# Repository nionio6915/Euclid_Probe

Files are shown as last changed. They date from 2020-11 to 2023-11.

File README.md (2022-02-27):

# EUCLID PROBE

The highly accurate, magneticaly coupled Z-Probe that is not affected by bed temp, bed material, magnetism or surface treatment.   

The probe can be configured to be used as Z-endstop, be manually or automatically deployed via gcode macros, and can take advantage of the firmware's probe pickup detection scheme to ensure pickup/release. It uses screw attached magnets for both mechanical coupling and for electrical contact. The Z-Probe circuit is completed when the probe is attached. 

The unique dock design securely captures the probe, providing secure and reliable docking and undocking. 

# We have moved all documentation to https://www.euclidprobe.com  
# All data and source files will remain here and be linked from here 

YouTube Channel - https://www.youtube.com/channel/UCIUXRiUfHCOrqRxitcH9O6g

Discussion and support is available as a subgroup to the CroXY Discord- https://discord.gg/jfnVrUx2uK croxy  

Parts kits and fully assembled probes are available for purchase at www.euclidprobe.com. 

The most current info, including printable dock and mount files are also hosted at www.euclidprobe.com.

**<br />This work is licensed under a <a rel="license" href="http://creativecommons.org/licenses/by-nc-sa/4.0/">Creative Commons Attribution-NonCommercial-ShareAlike 4.0 International License</a>.**

## Euclid Probe YouTube Channel 

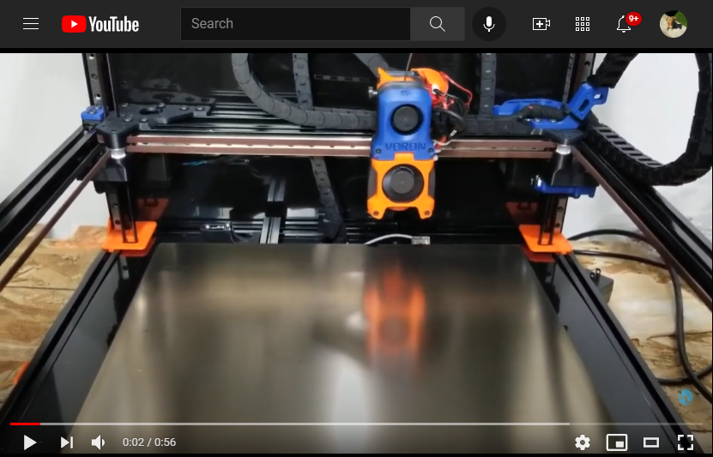
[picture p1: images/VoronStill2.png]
<a href="https://www.youtube.com/channel/UCIUXRiUfHCOrqRxitcH9O6g" target="new"><br>Euclid Probe YouTube channel</br></a>

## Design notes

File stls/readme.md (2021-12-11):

## Repository of stl's for probe adapters and probe docks. 

CAD files in the CAD directory. 

Docks and adapters are designed to be printed at either 0.2mm or 0.3mm layer heights. The probe dock stl's are offered with both Print In Place supports and withought. The best probe deployment results seem to be had by printing the probe dock upside-down: in the event that the PCB bears against the top of the dock when being deployed, this would be the best, top surface of your print. The bottom of the well surface can be a little rough and uneven.  

Note: there is a 5x5mm pocket to insert an optional magnet or ferrous object to retain the probe in the dock. It is not required. This was utilized in early stages of development and remains a legacy for now. 

**The design of your dock is critical to the sucessfull attaching and detaching of the probe.** The Euclid Probe dock utilizes a well, so that when the probe is stripped from the carraige, it is retained by the stops. Upon probe pickup, the probe PCB must clear the exit slots. Adjust the elevation of either the carraige in the deployment gcode or adjust the dock so that in the coupled condition, the probe will slide out without interference.   

## Mounts
**BLTouch Adapter Mount**
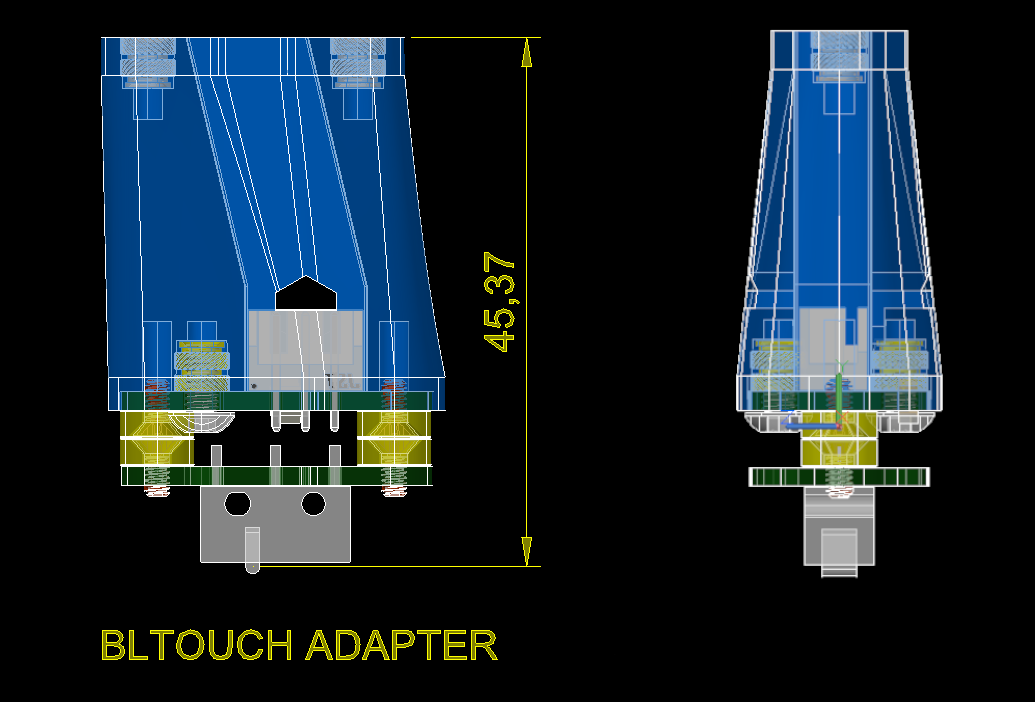
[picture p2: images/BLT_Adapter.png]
BL Touch Adapter
   

**Fixed Frame Dock**
2 Piece design, uses M3 screws and captive nuts to couple the parts. Vertical slots in the mount provide adjustability.     
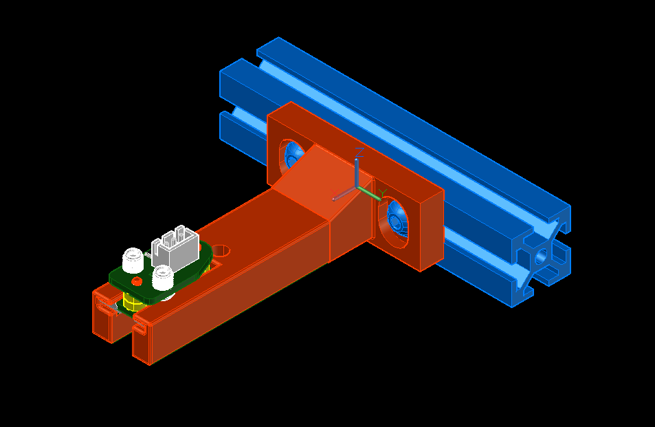
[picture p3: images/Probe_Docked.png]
Probe docked in Frame mounted fixed dock
  

**Movable Bed Dock**  
Uses long style, double taper heatserts for assembly. Mounts to the end of a 2020 bed support rail and is adjustable for height. Allows for interchangeble beds to fit under the mount. Requires a change the Z probe offset constant by the bed thickness on the fly. ( G31 Z-(bed thickness) )     
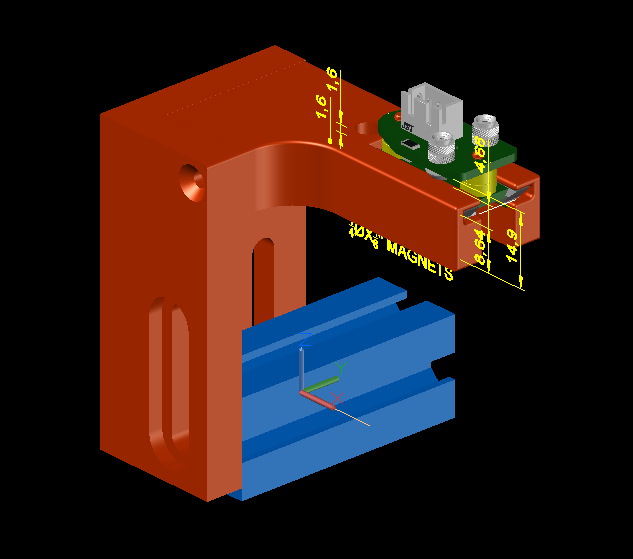
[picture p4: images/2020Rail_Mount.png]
2020 BBed Mount
 

**Dock stub for grafting into your own printer design the business end you need.**  
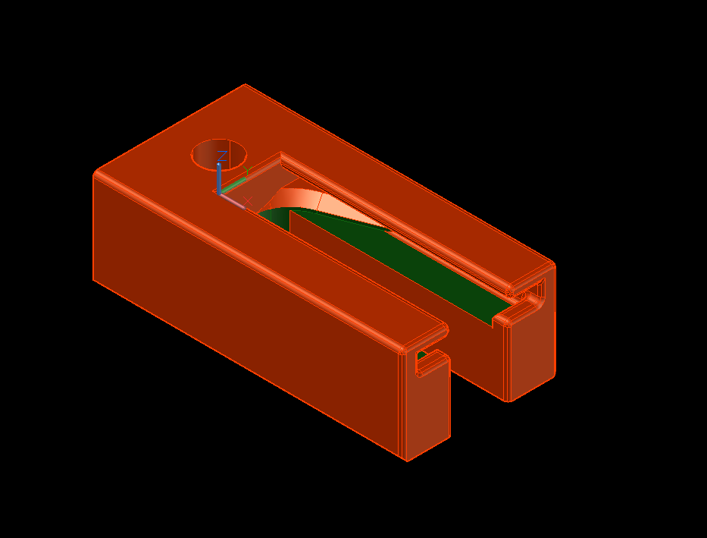
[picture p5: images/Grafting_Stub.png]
Grafting Stub
  

**Omron / Fotec Adapter mount**   
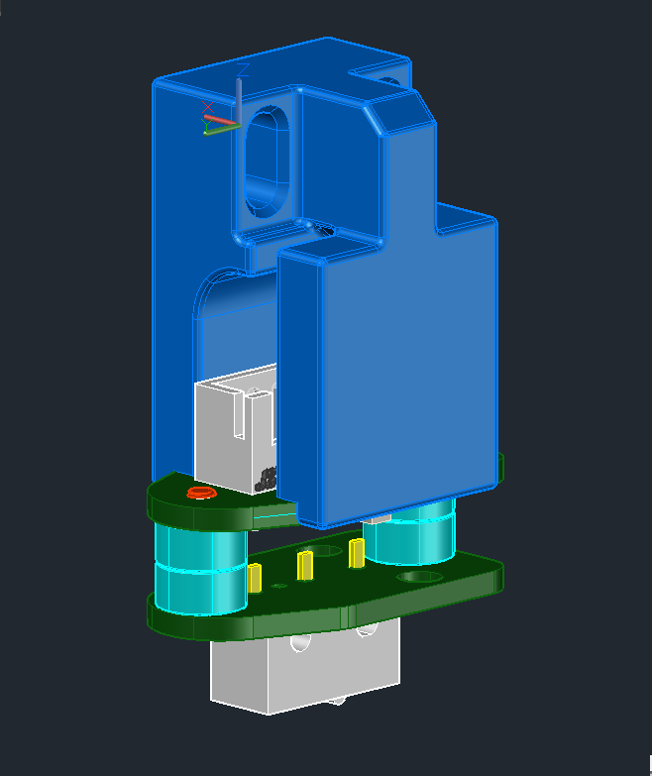
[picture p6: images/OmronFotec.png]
Omron-Fotek
  

**Omron / Fotec 90 Degree Rotation Adapter mount**   
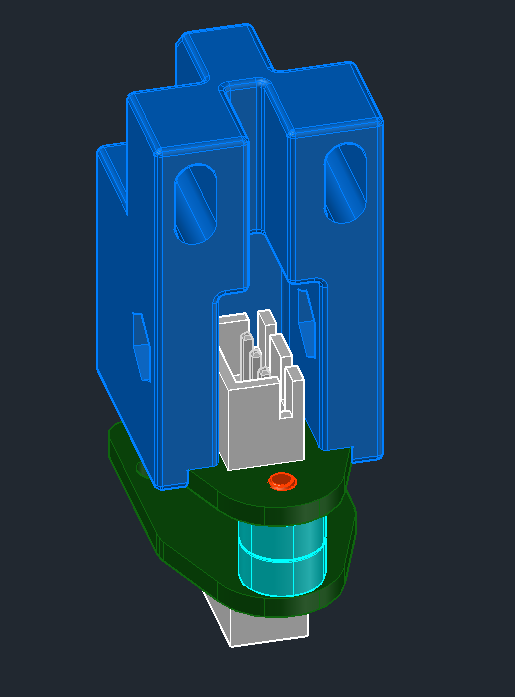
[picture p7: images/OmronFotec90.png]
Omron-Fotek
  

**Railcore Dock & Carriage Adapter**  
Dock based on work originally developed by FeNix. Mount attaches to the carraige plate and is slotted for adjustability. 
Railcore dock is a 2 piece design for adjustability, still under development due to all the variations of Railcore design. Provided with both heatsert and tapped hole options.  
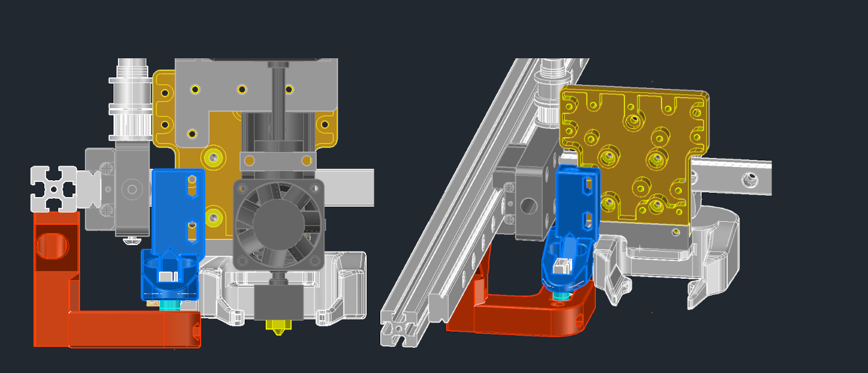
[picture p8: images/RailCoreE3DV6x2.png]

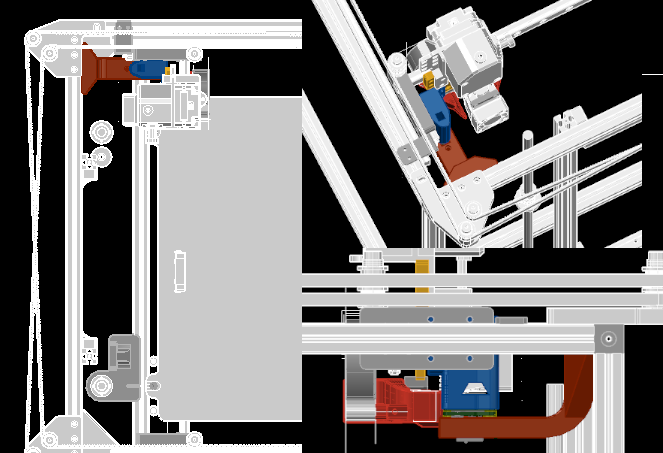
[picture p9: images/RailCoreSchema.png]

iso

**Voron Afterburner V4 User Mod**  
Recessed mount for Euclid probe inte the bottom of the carraige parts, pushing the probed frurther back in Y direction. 
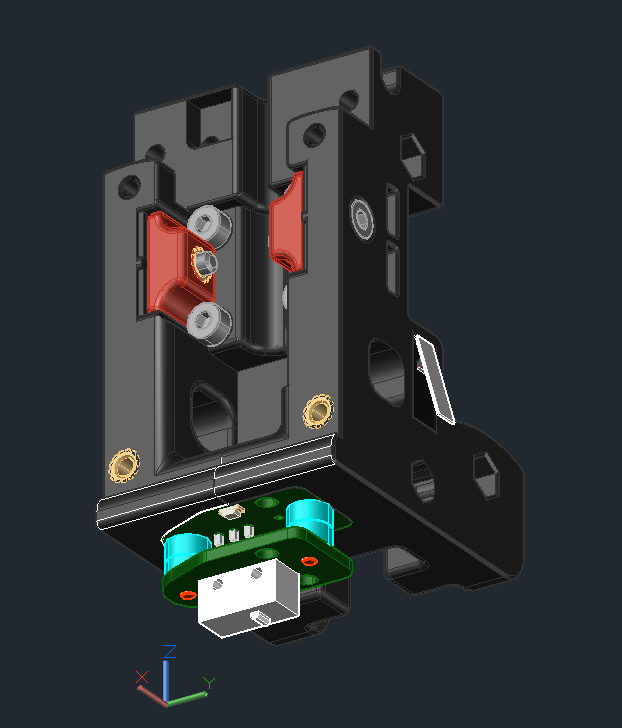
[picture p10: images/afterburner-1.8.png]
 

**Voron 2.4 Frame Mount**  
This mount mounts to the main frame of the printer. Users are cautioned that the probe will always be in the plane of the motion system, and there is always a prossibility of errant probe pickup compared to the bed mounted dock below.   
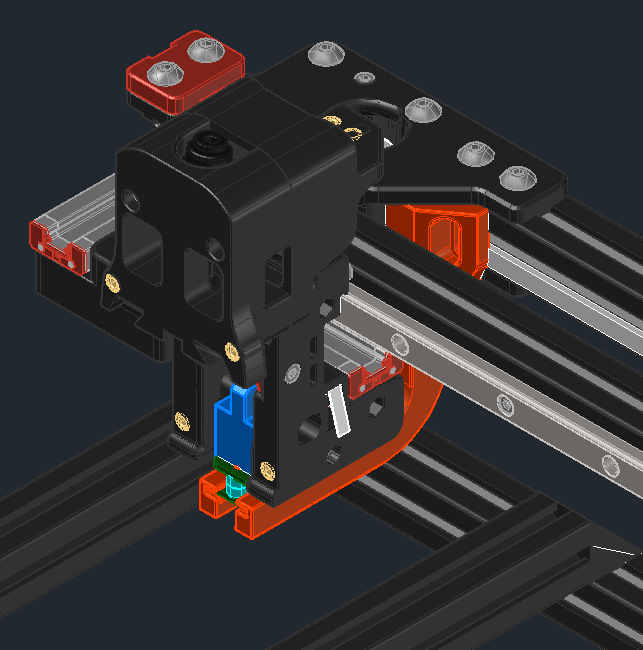
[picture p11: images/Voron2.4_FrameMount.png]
  
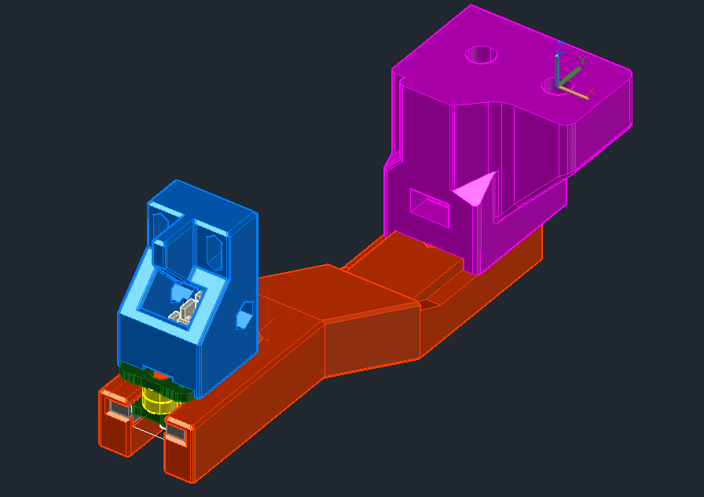
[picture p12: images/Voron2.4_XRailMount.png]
  

**Voron 2.4 Bed Rail Mount**
This mount attaches to the print bed mounting rail. The potential for errant probe pickup is reduced to the Z elevation of the magnet strengths.   
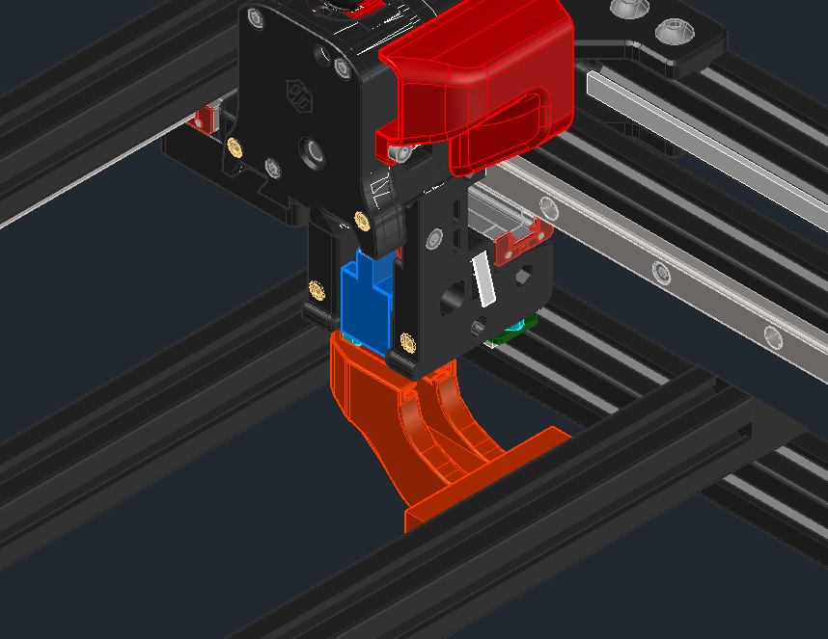
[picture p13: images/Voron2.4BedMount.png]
   
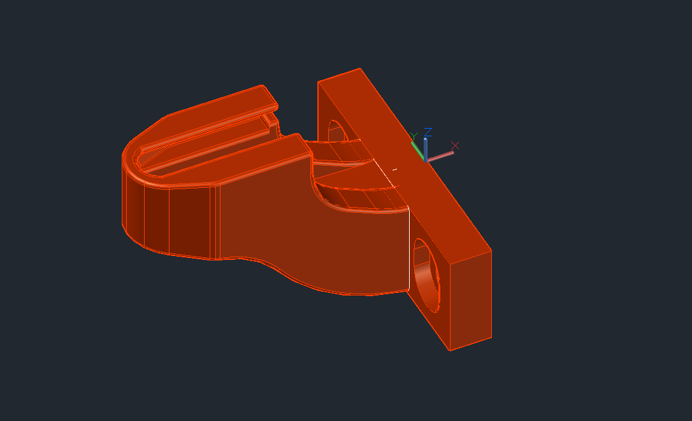
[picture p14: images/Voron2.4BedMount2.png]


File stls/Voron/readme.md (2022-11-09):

# Repository of stl's for Voron printers

## Clockwork1 - 2xMGN9 Rail - Afterburner Native Mounts
The left and right halves of the Afterburner carriage are modified to accept the probe with M3 screws and heatserts from underneath. Fine tuning and tweaking credited to garbqgebag.  
AB1  
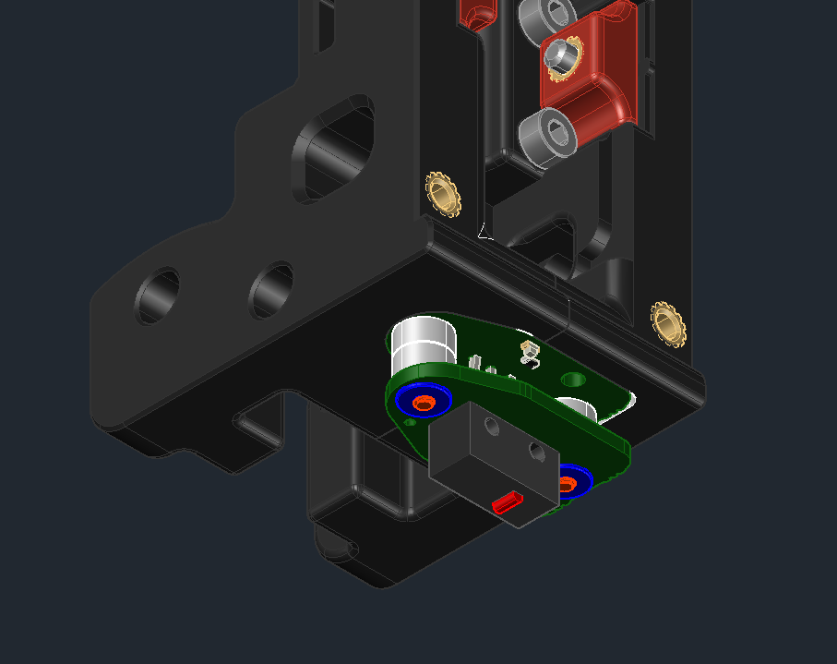
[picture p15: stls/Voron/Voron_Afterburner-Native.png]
  
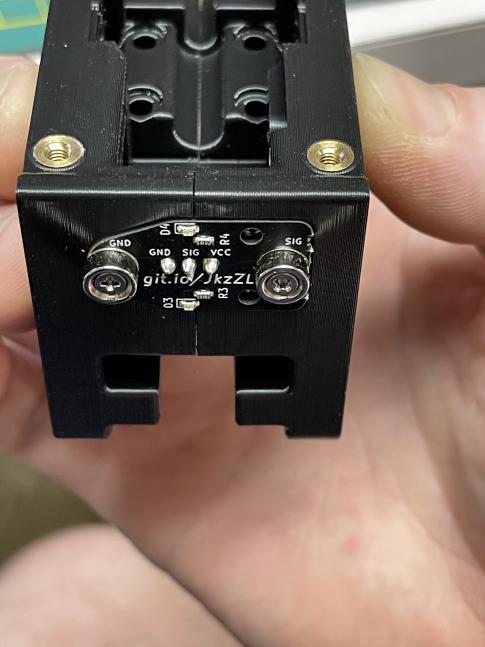
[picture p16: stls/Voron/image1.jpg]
AB3

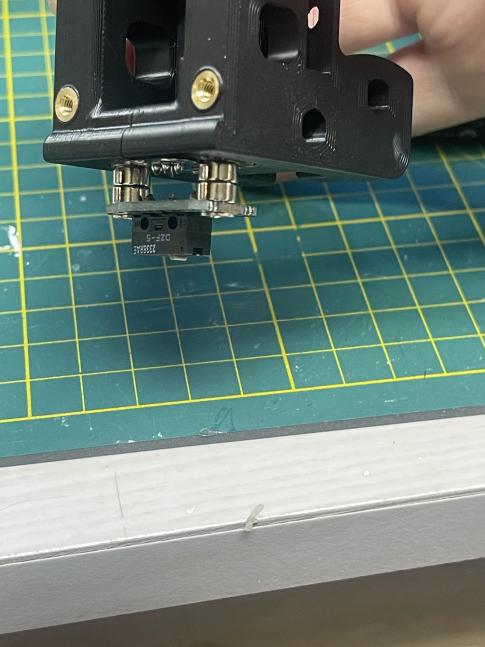
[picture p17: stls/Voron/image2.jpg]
AB4


## Clockwork1 - MGN12 Rail - Trident Native Mounts
The left and right halves of the Afterburner carriage are modified to accept the probe with M3 screws and heatserts from underneath. Fine tuning and tweaking credited to garbqgebag.  
AB1  
AB2  
AB3
AB4

## Omron Mounts
The standard Omron mount is 0 degree relative rotation to the mounting face of the Omron device. Adjustment slots are similar to the original device.  Designed to be printed upside-down without supports.  

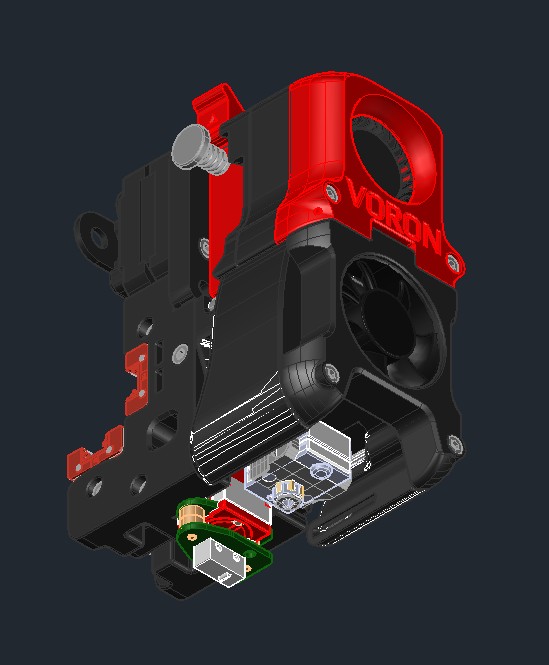
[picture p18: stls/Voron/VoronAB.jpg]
Omron-Fotek0
  
Omron-Fotek

The Omron mount also exists in 90 degree version with the probe pointing backwards instead of sideways.

## Voron Trident Dock Mount  
The mount attaches with longer screws in the native holes of the left side motor bracket and clears the radius of the cable chain. 3-M5x20 screws required.     
The dock attaches to the mount with an M5 nut dropped in the keyholed channel and thru-bolts with an M5x20 screw. Adjust the elevation as required to allow for a clean exit of the probe PCB. Fine tuning and tweaking credited to Dattas.
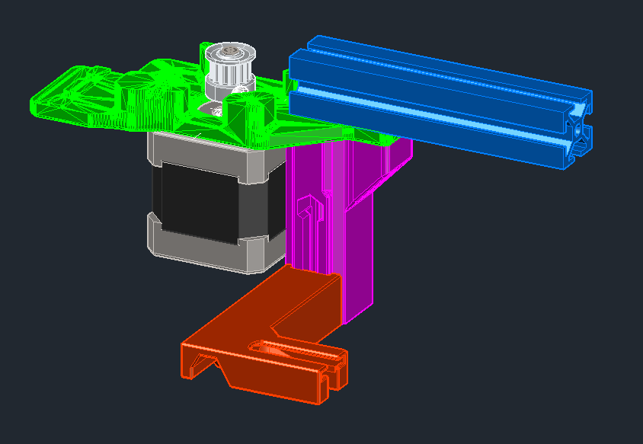
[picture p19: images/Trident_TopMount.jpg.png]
Trident


## Gantry Dock & Mount
This dock is orientated in the X direction and attaches to the rear extrusion of the gantry, in the native holes of the left side motor bracket. Requires the use of the Omron mount or Native Afterburner Carriage. Attaches with longer screws, M5x16. Lateral Y adjustment via the thru-bolt on the bottom, M5x16. Fine vertical adjustment via the slotted holes in the Omron mount or with shims between the Y adjuster. Currently untested and unproven to our knowledge- please contact us if difficulties are encountered. This configuration should be compatible with the other detachable probe macros for Voron.  
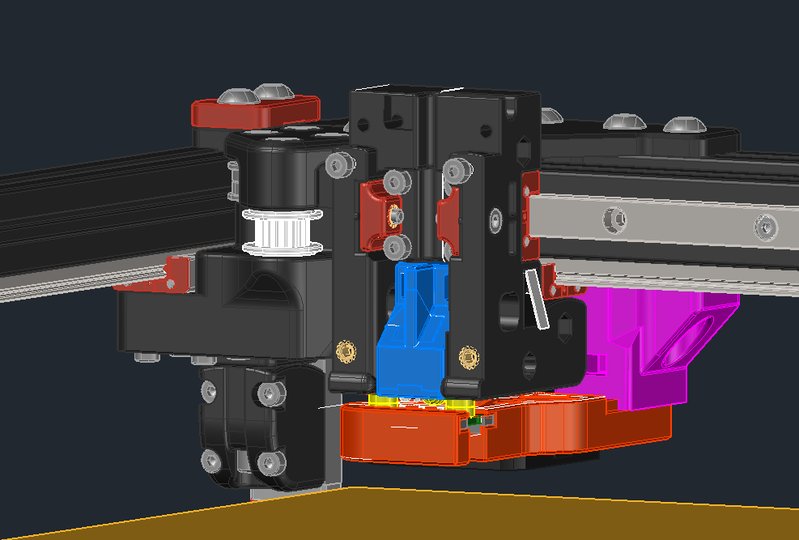
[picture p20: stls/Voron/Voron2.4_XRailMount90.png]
XRail2

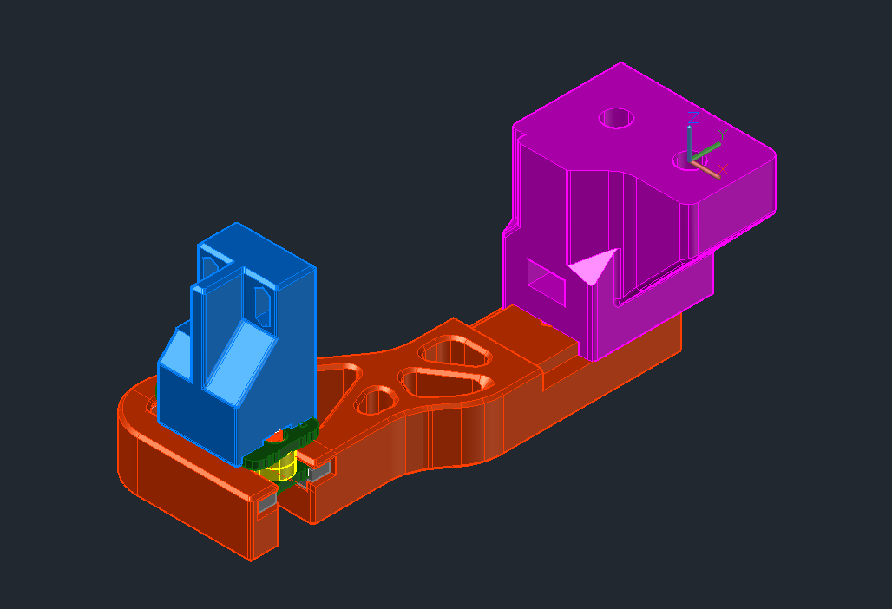
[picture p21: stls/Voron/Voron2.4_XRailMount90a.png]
XRail


## 90 Degree  Gantry Dock & Mount
This mount attaches to the rear extrusion of the gantry, attaches with longer screws, M5x16, in the native holes of the left side motor bracket. Requires the use of the Omron90 mount. Lateral adjustment buy the thru-bolt on the bottom, M5x16. Fine vertical adjustment via the slotted holes in the Omron mount.  This configuration should be compatible with the other detachable probe macros for Voron orientated in the Y direction. 

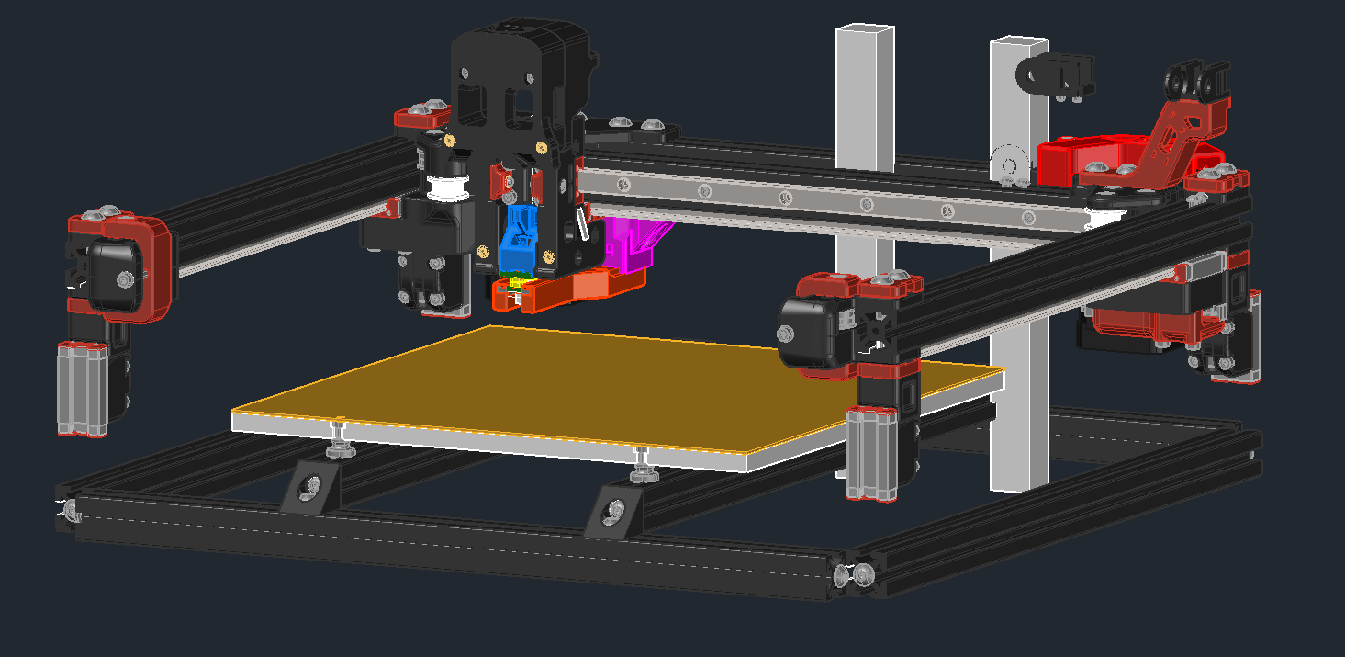
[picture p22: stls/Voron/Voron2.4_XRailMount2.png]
XRail2

XRail

## Voron 2.4 Bed Rail Mounted Dock  
The bed mounts are provided in 2 heights to suit the overall stack height of the bed plate and printing surfaces. This dock has been tested by multiple users. Fine tuning and tweaking credited to kageurufu.

The stls are provided to print 'nose' down and have minimal print in place supports to ensure that the back shoulder is printed and aligned. 

The bed rail mount uses 2-M5x16 screws and extrusion nuts to attach to either side of the extrusions that support the bed. 

There are 2 hex-shaped cross holes to the main mounting screws- these are provided to insert M3 screws to use as fine adjusters without tapping. They can be M3 setscrews and left in place or any M3 screw used temporarily.  
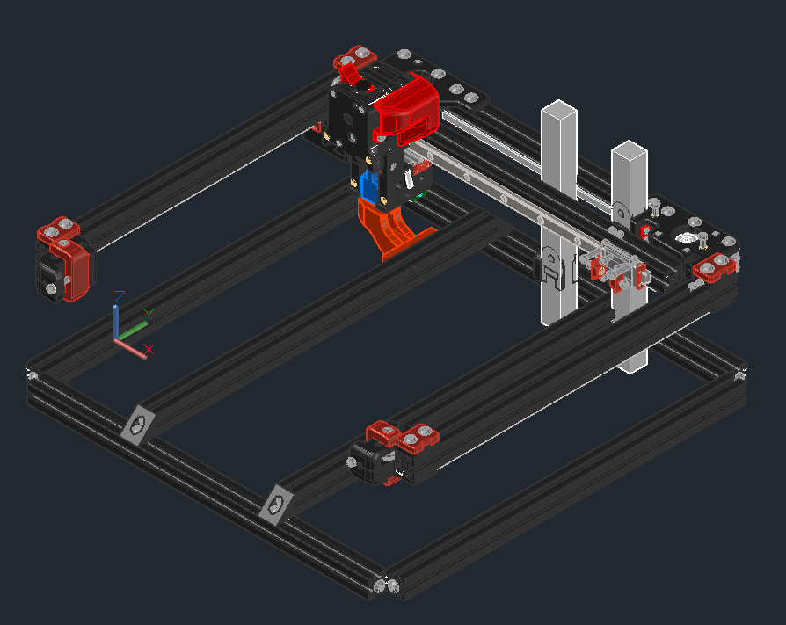
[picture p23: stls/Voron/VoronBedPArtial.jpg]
  
  
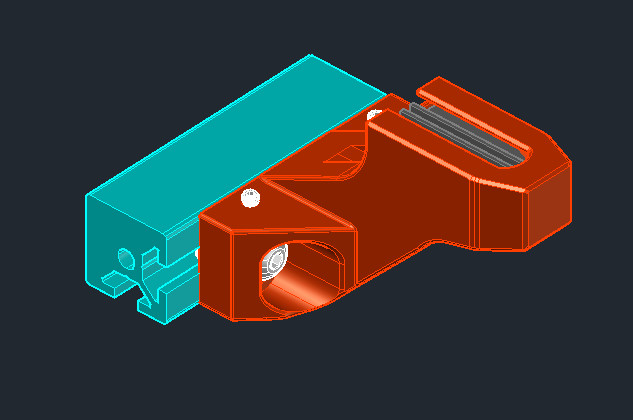
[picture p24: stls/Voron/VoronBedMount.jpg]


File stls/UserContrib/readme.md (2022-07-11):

No short cover that protect the probe when docked
Contributor: akhamar
https://github.com/akhamar/Euclid_Probe

euclid probe : slim mount
Conributor: v6cl
https://github.com/v6cl/My-Voron2.4-Customs/tree/main/euclid_mount_slim

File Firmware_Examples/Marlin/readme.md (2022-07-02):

Marlin configuration is highly dependent on the controller board used. the following is a general outline of the hardware definition only. 
The full probe deployment and retraction, part of the Configuration.h and Config_adv, are illustrated in the Ender3 config files. 
## For the most up to date information, see www.euclidprobe.com

//===========================================================================
//============================== Endstop Settings ===========================
//===========================================================================
// @section homing

// Specify here all the endstop connectors that are connected to any endstop or probe.
// Almost all printers will be using one per axis. Probes will use one or more of the
// extra connectors. Leave undefined any used for non-endstop and non-probe purposes.
#define USE_XMIN_PLUG
#define USE_YMIN_PLUG
#define USE_ZMIN_PLUG
...
#define USE_ZMAX_PLUG // ENABLE IF USING Z_MAX FOR PROBE

......................

// Mechanical endstop with COM to ground and NC to Signal uses "false" here (most common setup).
...
#define Z_MIN_PROBE_ENDSTOP_INVERTING false // Set to true to invert the logic of the probe.

......................

//===========================================================================
//============================= Z Probe Options =============================
//===========================================================================
// @section probes

//
// See https://marlinfw.org/docs/configuration/probes.html
//

/**
 * Enable this option for a probe connected to the Z-MIN pin.
 * The probe replaces the Z-MIN endstop and is used for Z homing.
 * (Automatically enables USE_PROBE_FOR_Z_HOMING.)
 */
// #define Z_MIN_PROBE_USES_Z_MIN_ENDSTOP_PIN // 

...

/**
 * Z_MIN_PROBE_PIN
 *
 * Define this pin if the probe is not connected to Z_MIN_PIN.
 * If not defined the default pin for the selected MOTHERBOARD
 * will be used. Most of the time the default is what you want.
 *
 *  - The simplest option is to use a free endstop connector.
 *
 *  - RAMPS 1.3/1.4 boards may use the 5V, GND, and Aux4->D32 pin:
 *    - For simple switches connect...
 *      - normally-closed switches to GND and D32.
 *      - normally-open switches to 5V and D32.
 */
#define Z_MIN_PROBE_PIN PA4 // Pin 32 is the RAMPS default
                            // Our Ender-3 test printer with Creality 4.2.2 controller
                            // uses the filament runout sensor connector 

......................
The best way we have found to deploy Euclid Probe under Marlin is with the Allen Probe scheme built into Marlin. The predefined sequence of points and movements to deploy and retract work well natively without any additions.
Following is the probe definition only.

//
// For Z_PROBE_ALLEN_KEY see the Delta example configurations.
//
/**
 * Allen key retractable z-probe as seen on many Kossel delta printers - https://reprap.org/wiki/Kossel#Automatic_bed_leveling_probe
 * Deploys by touching z-axis belt. Retracts by pushing the probe down. Uses Z_MIN_PIN.
 */
#define Z_PROBE_ALLEN_KEY

......................
/
// For Z_PROBE_ALLEN_KEY see the Delta example configurations.
//
// 
/**
 * Allen key retractable z-probe as seen on many Kossel delta printers - https://reprap.org/wiki/Kossel#Automatic_bed_leveling_probe
 * Deploys by touching z-axis belt. Retracts by pushing the probe down. Uses Z_MIN_PIN.
 */
#define Z_PROBE_ALLEN_KEY

#if ENABLED(Z_PROBE_ALLEN_KEY)
  // 2 or 3 sets of coordinates for deploying and retracting the spring loaded touch probe on G29,
  // if servo actuated touch probe is not defined. Uncomment as appropriate for your printer/probe.

  #define Z_PROBE_ALLEN_KEY_DEPLOY_1 { 165, 50, 10 }  // Dock side approach position
  #define Z_PROBE_ALLEN_KEY_DEPLOY_1_FEEDRATE XY_PROBE_FEEDRATE

  #define Z_PROBE_ALLEN_KEY_DEPLOY_2 { 165, 14, 0 }  // Mount over dock position for probe coupling
  #define Z_PROBE_ALLEN_KEY_DEPLOY_2_FEEDRATE (XY_PROBE_FEEDRATE)/10

  #define Z_PROBE_ALLEN_KEY_DEPLOY_3 { 130, 14, 0 } // Translate probe out of dock 
  #define Z_PROBE_ALLEN_KEY_DEPLOY_3_FEEDRATE XY_PROBE_FEEDRATE

  #define Z_PROBE_ALLEN_KEY_DEPLOY_4 { 130, 14, 15 } // Vertically lift probe up to clear bed & dock 
  #define Z_PROBE_ALLEN_KEY_DEPLOY_4_FEEDRATE XY_PROBE_FEEDRATE

  #define Z_PROBE_ALLEN_KEY_STOW_1 { 130, 14.0, 10.0 } // Move the probe into X,Y dock approach position
  #define Z_PROBE_ALLEN_KEY_STOW_1_FEEDRATE XY_PROBE_FEEDRATE

  #define Z_PROBE_ALLEN_KEY_STOW_2 { 130, 14.0, 0.0 } // Move probe down to dock entry position
  #define Z_PROBE_ALLEN_KEY_STOW_2_FEEDRATE (XY_PROBE_FEEDRATE)/10

  #define Z_PROBE_ALLEN_KEY_STOW_3 { 165.0, 14.0, 0.0 } // Move probe into dock
  #define Z_PROBE_ALLEN_KEY_STOW_3_FEEDRATE XY_PROBE_FEEDRATE

  #define Z_PROBE_ALLEN_KEY_STOW_4 { 165.0, 50.0, 0.0 } // Swipe probe off of mount 
  #define Z_PROBE_ALLEN_KEY_STOW_4_FEEDRATE XY_PROBE_FEEDRATE

#endif // Z_PROBE_ALLEN_KEY

......................

......................

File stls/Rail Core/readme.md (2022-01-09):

## General Railcore Plan & Dock Offset Dimensions  
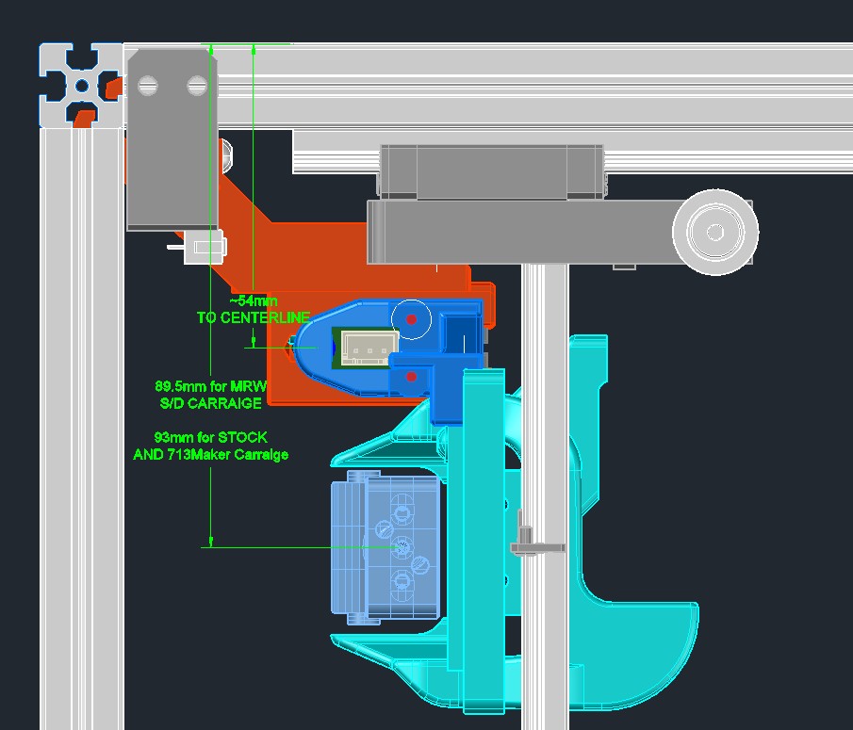
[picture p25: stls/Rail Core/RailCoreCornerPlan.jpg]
plan view
<br>  
X Elev<br>  
Y Elev<br>  

## Petsfang Dock & Mount Dimensions  
PFang0<br>  
PFang1<br>  

## Top Mount Dock & Mount Dimensions  
PFang1<br>

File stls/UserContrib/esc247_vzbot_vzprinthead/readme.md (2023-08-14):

## Custom VZbot VZ-Printhead mount
I've created a custom mount for the Euclid Probe for the VZ-Printhead. (Euclid mount VZ-printhead v5)

It needs to be assembled onto the 5015 fan at the back.

The dock that I used is the VoronGantyMountRev_4 filed down a little bit along with the RailCoreTopMountLong, assembled the other way to make the Mount fit.

The image should make the assembly clearer.

I've added the docks from the other repos here to make it easier to find the full assembly.


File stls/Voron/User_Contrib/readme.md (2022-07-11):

LGX adapter for VORON MGN12 X-carrige
https://www.printables.com/model/240124-lgx-adapter-for-voron-mgn12-x-carrige/files
A new adapterplate for mgn12 x-carrige that u screw from the front

xp1ratex
Euclid_x_carriage_mgn12_m3_locknut_for_new_lgx_adapter.3mf
x_carriage_mgn12_m3_locknut_for_new_lgx_adapter.3mf
LGX_adapter_1piece_screws_from_front.3mf

Stealthburner
euclid_mgn12_cw2_right.3mf
euclid_mgn12_cw2_left.3mf

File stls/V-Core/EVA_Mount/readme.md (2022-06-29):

Initial EVA3 mount and dock created by Discord user slebed.

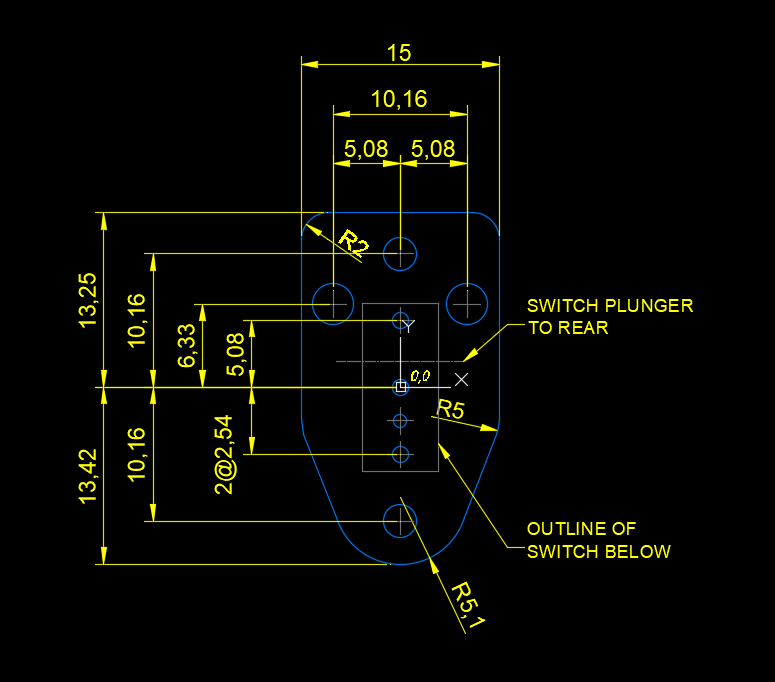
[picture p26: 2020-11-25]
images/board-dims.png

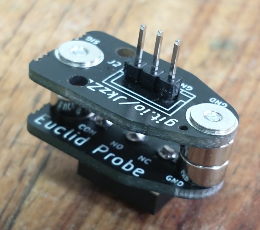
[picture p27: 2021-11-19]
images/IsoTN.png

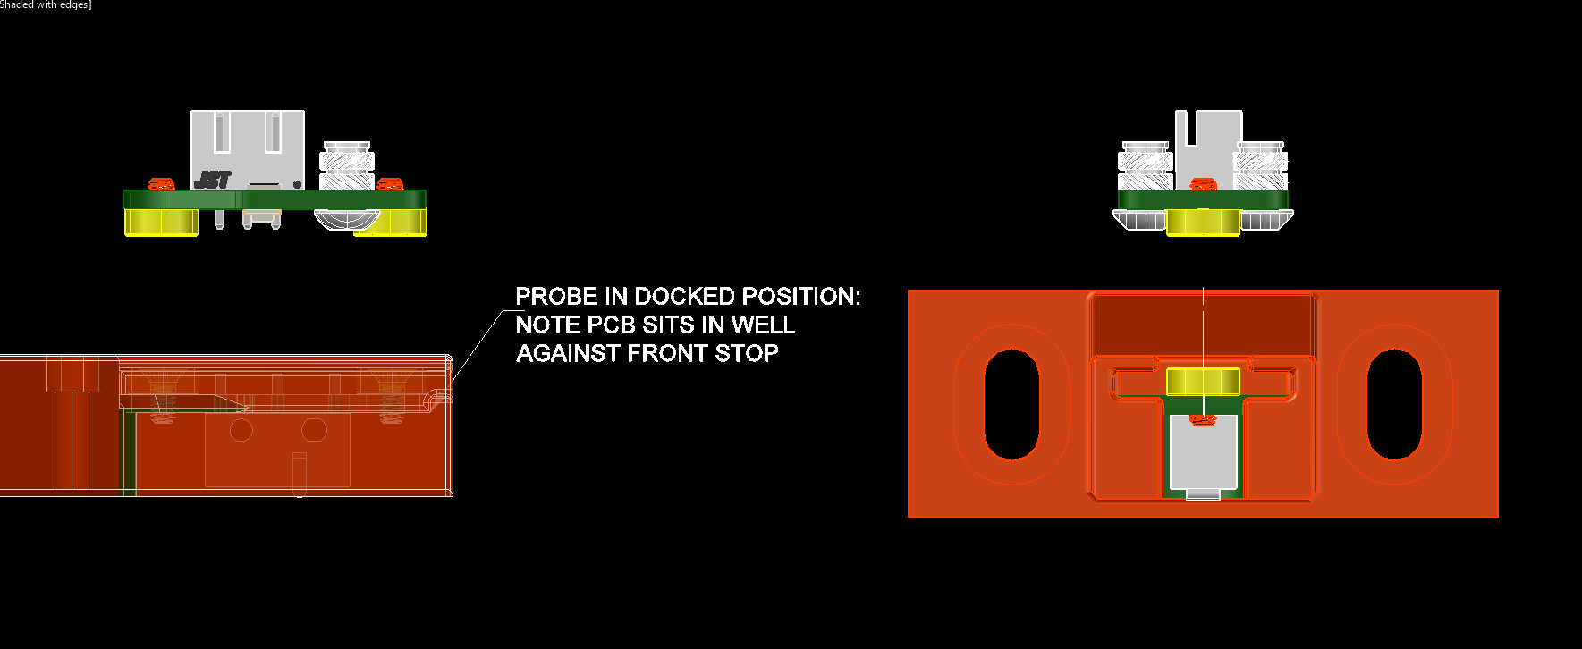
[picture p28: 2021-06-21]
images/Front-Undocked.png

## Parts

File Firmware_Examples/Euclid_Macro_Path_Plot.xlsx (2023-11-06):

 |  | X | Y
bed_min | [ | 0 | 0 | ]
bed_max | [ | 350 | 350 | ]
 |  |  |  |  |  |  | 0 | 0 | 235 | 349 | Z Stop
 |  |  |  |  |  |  | 0 | 0 | 35 | 300 | Preflight
variable_position_preflight | [ | 35 | 300 | ] | # | position for probe to have clear path to dock | 0 | 350 | 35 | 320 | Dock Side
variable_position_side | [ | 35 | 320 | ] | # | position for probe to have clear path to dock | 350 | 350 | 35 | 349 | Dock
variable_position_dock | [ | 35 | 349 | ] | # | position for probe near dock to swipe on/off. | 350 | 0 | 70 | 349 | Dock Exit
variable_position_zstop | [ | 235 | 349 | ] | # | position for dock position | 0 | 0 | 175 | 175 | Bed Center
 |  |  |  |  |  |  | 0 | 0 | 150 | 347 | Nozzle Wiper
## exit/re-entry staging |  |  |  |  |  |  | 0 | 0 | 235 | 349 | Z Stop
variable_position_exit | [ | 70 | 349 | ] | # | position for zstop position | 0 | 0 | 235 | 349
nozzle_brush | [ | 150 | 347 | ] |  | position for nozzle brush

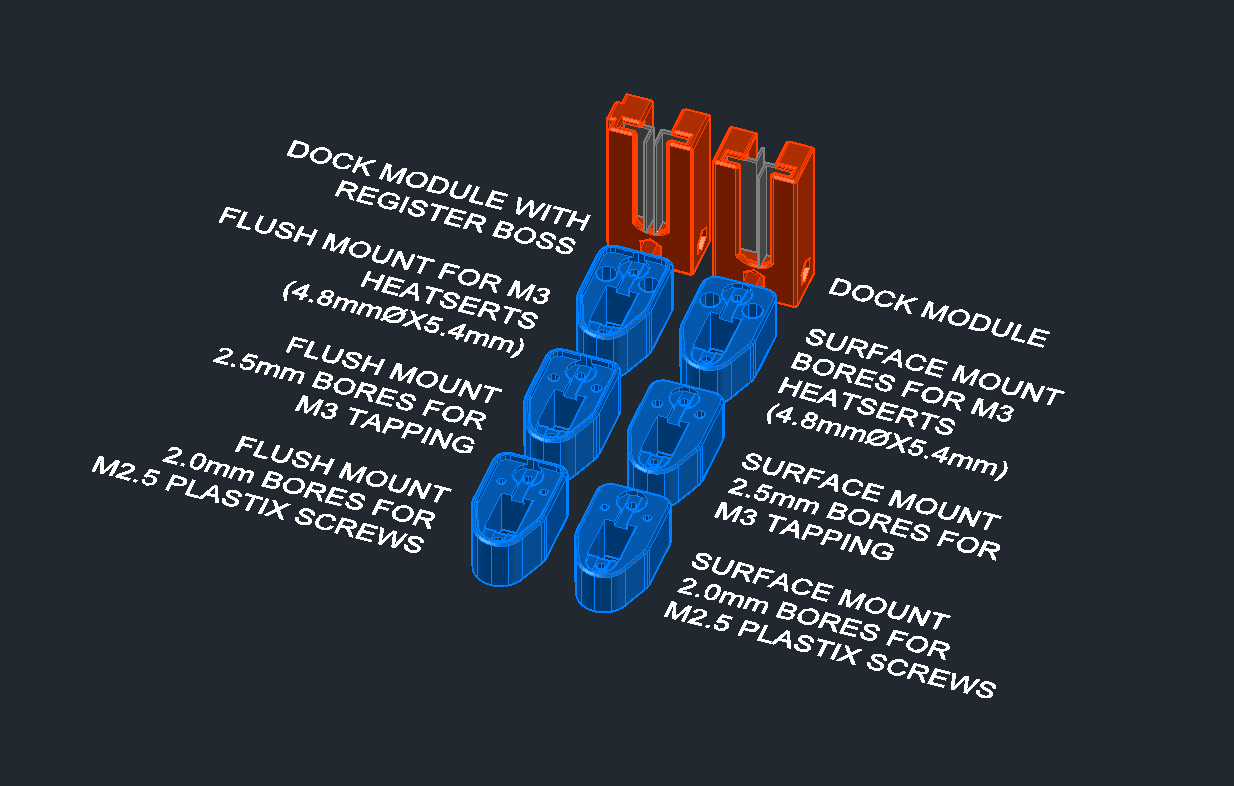
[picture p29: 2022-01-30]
CAD/Building_Blocks/02_Modular_Parts.png

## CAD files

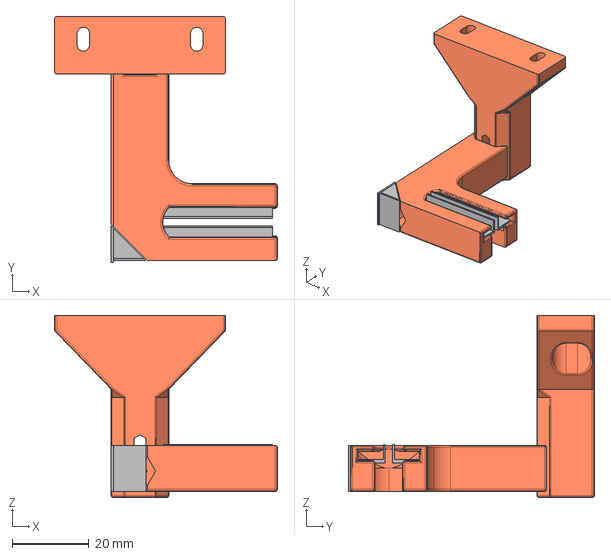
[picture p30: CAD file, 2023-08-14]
CAD/RailCore/RailCore_TopMountDock_Assy.stp
58.0 x 64.0 x 47.4 mm

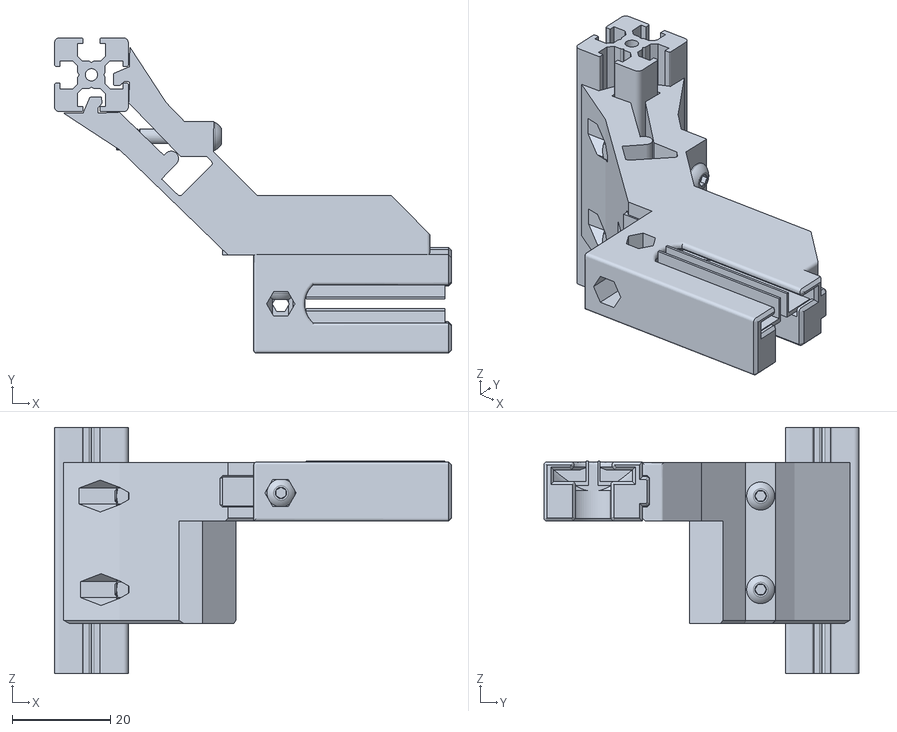
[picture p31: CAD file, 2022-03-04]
stls/Rail Core/RC_CornerMountAssembly.stl
80.6 x 64.0 x 50.0

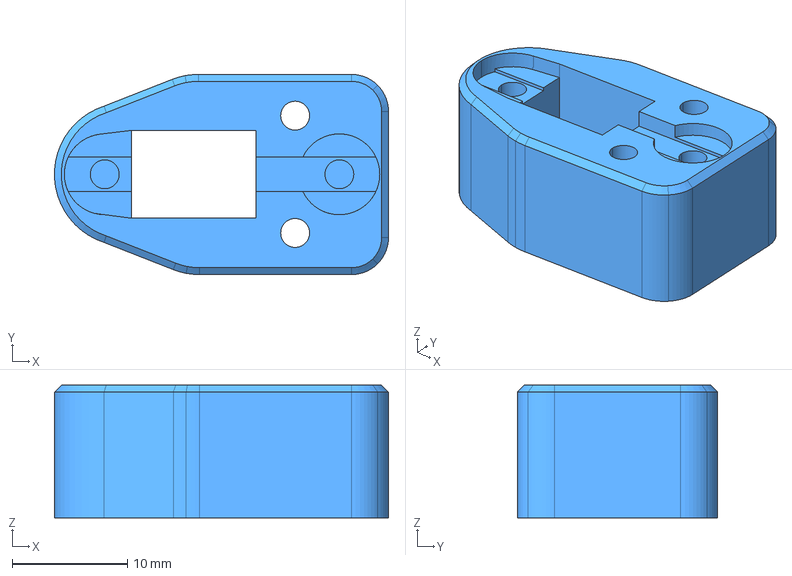
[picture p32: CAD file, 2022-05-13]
CAD/Building_Blocks/SingleM2.5Mount.stp
28.9 x 17.3 x 11.5 mm

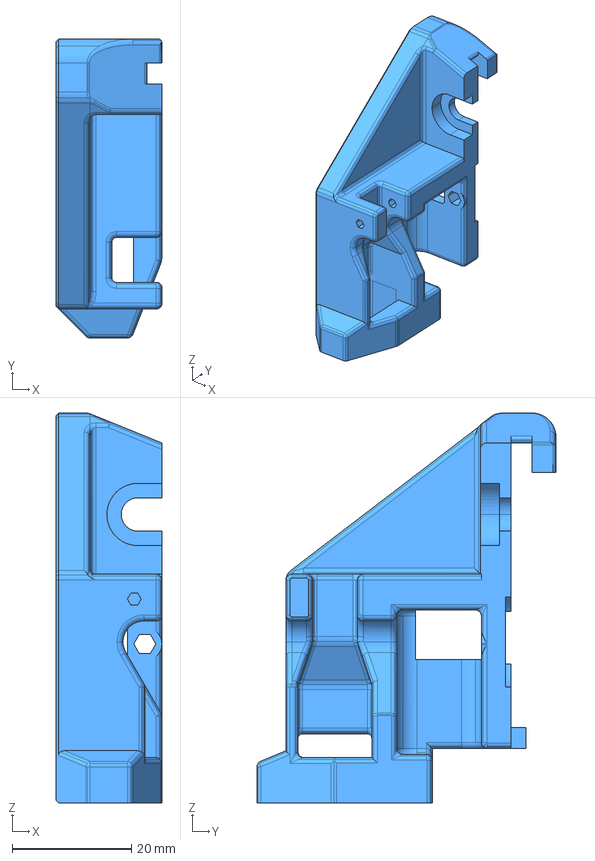
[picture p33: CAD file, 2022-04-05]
CAD/Ender/Ender5MountV7.stp
17.7 x 50.1 x 65.3 mm

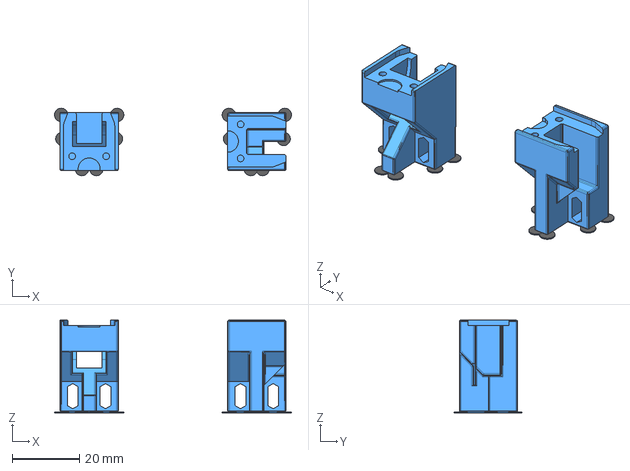
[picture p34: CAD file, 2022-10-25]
CAD/MountAdapters/OmronFotekV4.stp
70.7 x 20.1 x 27.7 mm

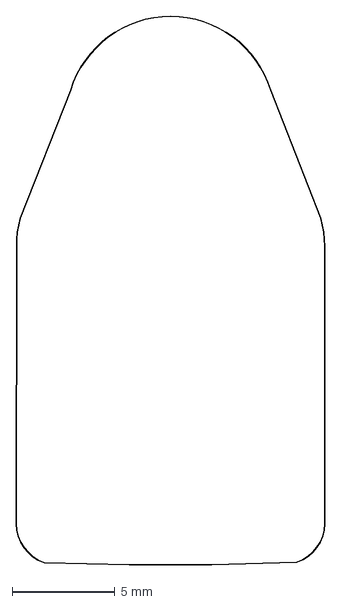
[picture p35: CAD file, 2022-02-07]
CAD/ProbeV4.dxf
15.0 x 26.7 mm

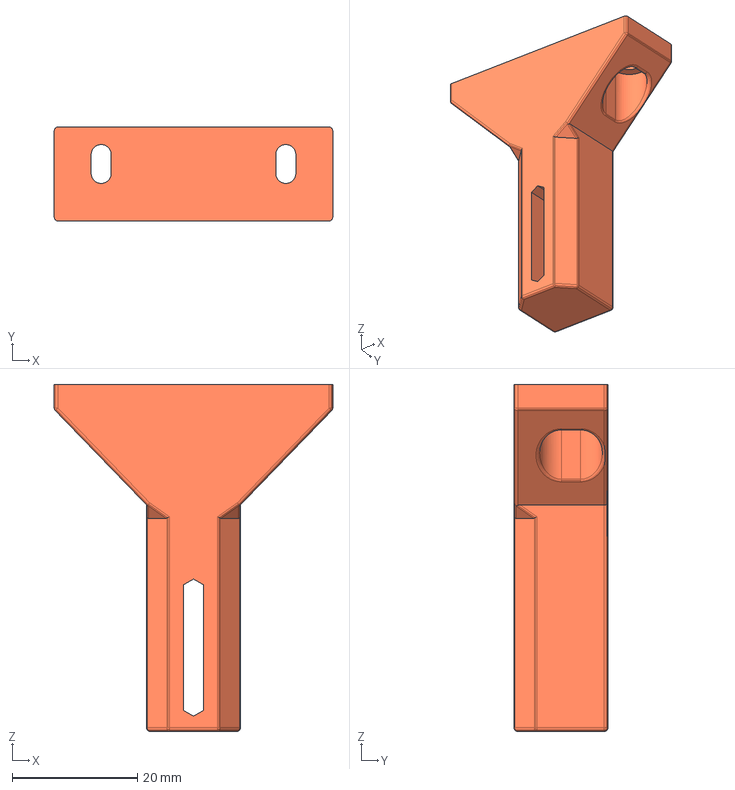
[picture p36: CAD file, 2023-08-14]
CAD/RailCore/RailCoreDockTopMount_TallerV3.stp
44.5 x 15.0 x 55.4 mm

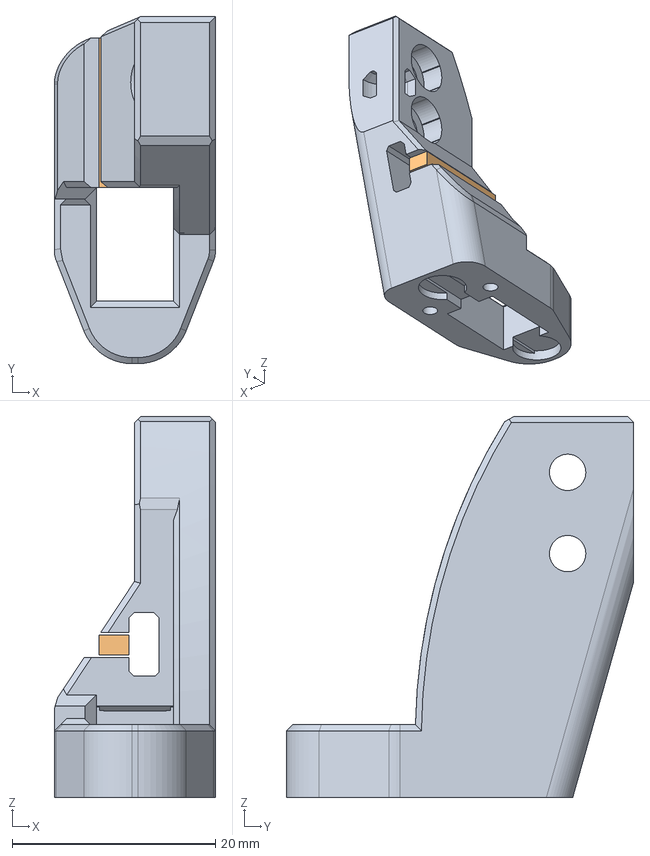
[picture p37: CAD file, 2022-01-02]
CAD/Rat-Rig V-Core/Euclid_EVA_MountV5.stp
15.9 x 34.2 x 37.5 mm

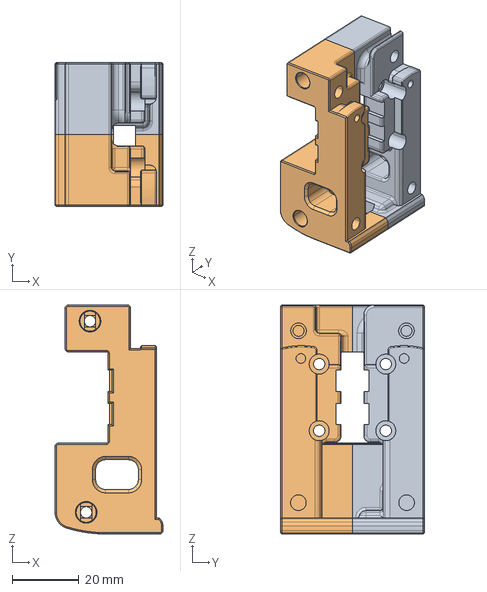
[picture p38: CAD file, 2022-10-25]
CAD/Voron/Euclid_CW2_MGN12X_Ver2.stp
32.4 x 43.2 x 68.8 mm

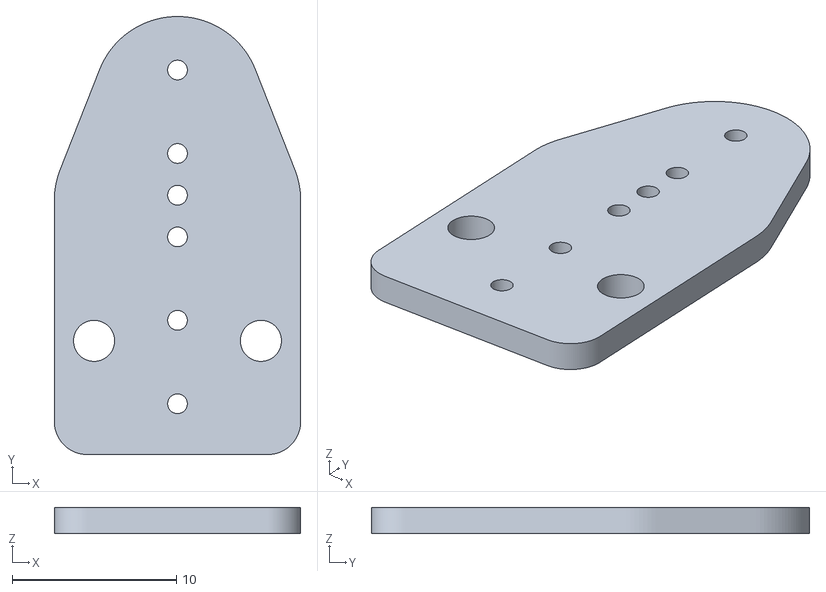
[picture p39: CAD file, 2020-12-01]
scad/board-with_pilotholes.stl
15.0 x 26.7 x 1.60

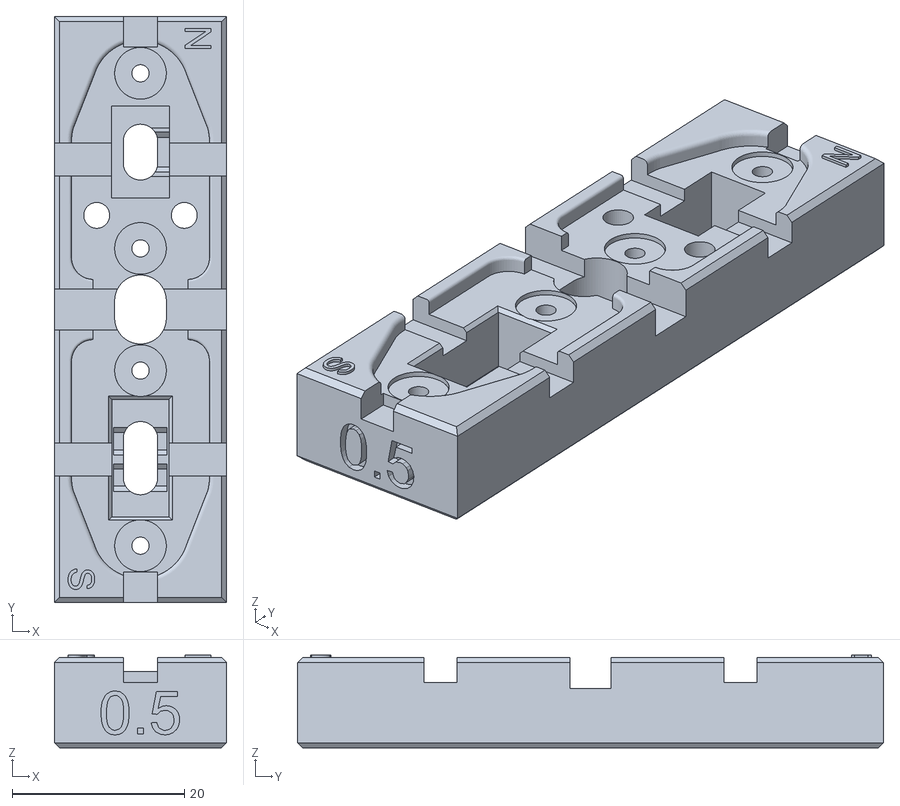
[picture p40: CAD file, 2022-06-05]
stls/Assembly Jigs/soldering_jigV5-0.5mm_margin.stl
20.0 x 68.0 x 10.8

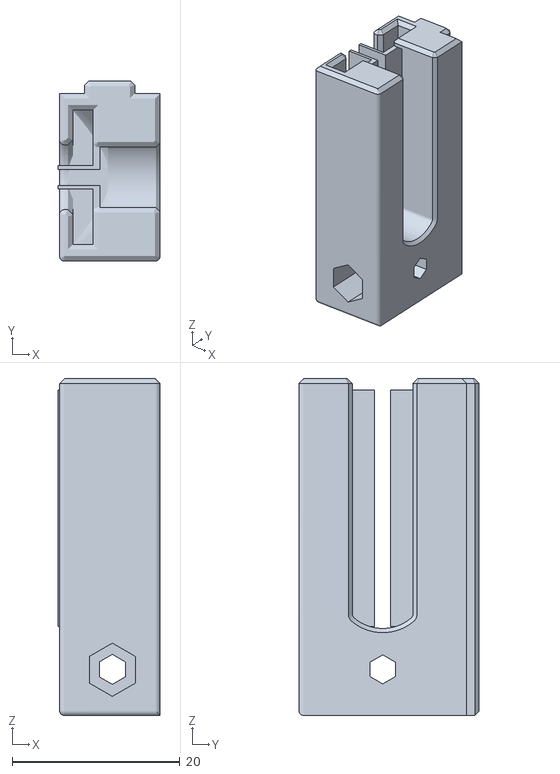
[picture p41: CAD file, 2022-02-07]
stls/Building Blocks/Grafting_Dock_RegBoss_V3.stl
12.2 x 21.5 x 40.2

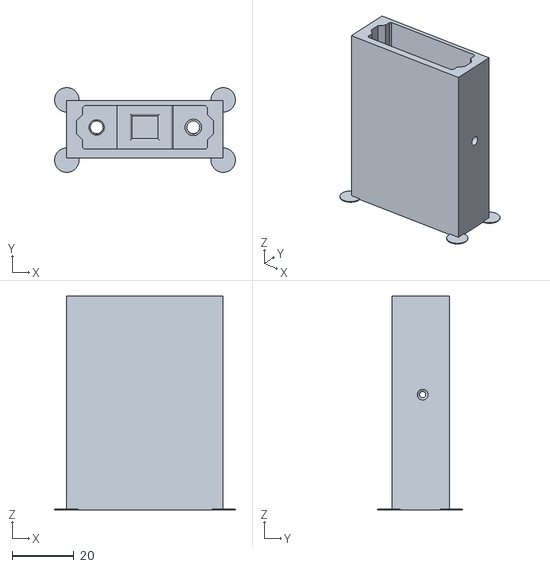
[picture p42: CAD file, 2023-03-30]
stls/Bump Dock/housing.stl
58.8 x 27.6 x 69.5

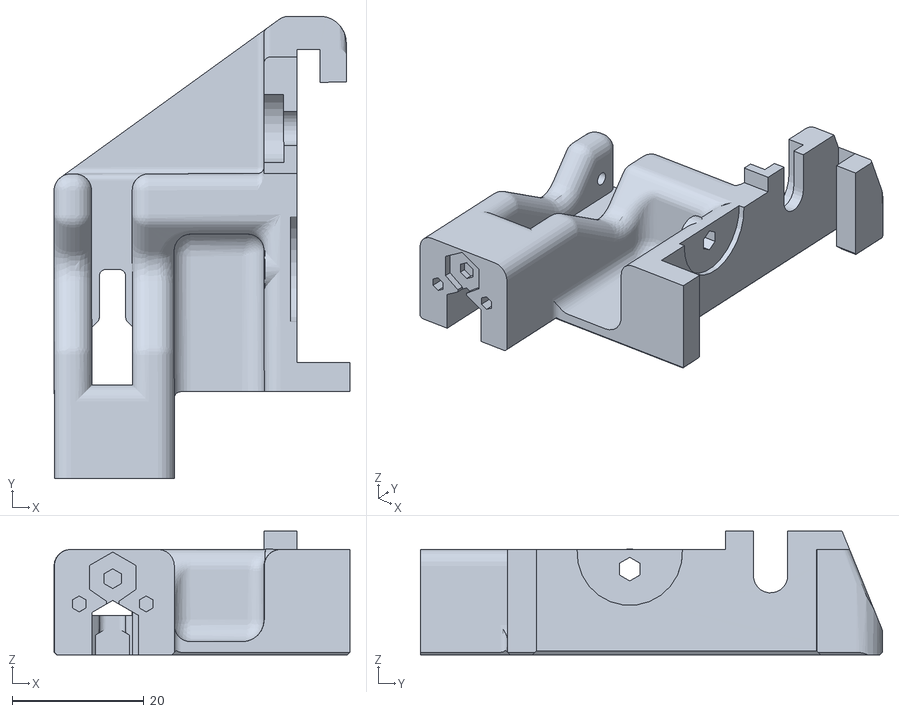
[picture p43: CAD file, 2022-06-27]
stls/Ender3/Ender3MountV8b.stl
44.9 x 70.1 x 18.8

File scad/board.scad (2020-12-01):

$fn=120;
use <./threads_v2p1.scad>
difference(){
hull() {
// nose
    translate ([0,8.32,0]) cylinder (h=1.6, r=5.1, center=true);
// back corners
    translate ([5.5,-11.25,0]) cylinder (h=1.6, r=2, center=true);
    translate ([-5.5,-11.25,0]) cylinder (h=1.6, r=2, center=true);
// side fillets
    translate ([2.5,2.25,0]) cylinder (h=1.6, r=5, center=true);
    translate ([-2.5,2.25,0]) cylinder (h=1.6, r=5, center=true);
}
translate ([0,0,0]) cylinder (h=6, r=0.6, center=true);
translate ([0,5.08,0]) cylinder (h=6, r=0.6, center=true);
translate ([0,-5.08,0]) cylinder (h=6, r=0.6, center=true);
translate ([0,2.54,0]) cylinder (h=6, r=0.6, center=true);
translate ([0,10.16,0]) cylinder (h=6, r=0.6, center=true);
translate ([0,-10.16,0]) cylinder (h=6, r=0.6, center=true);
translate ([5.08,-6.33, 0]) cylinder (h=6, r=1.25, center=true);
translate ([-5.08,-6.33, 0]) cylinder (h=6, r=1.25, center=true);

// ScrewHole(outer_diam=2.0, height=5, position=[0,10.16,-3], rotation=[0,0,0], pitch=0.4, tolerance=0.4) children();
// ScrewHole(outer_diam=2.0, height=5, position=[0,-10.16,-3], rotation=[0,0,0], pitch=0.4, tolerance=0.4) children();
// ScrewHole(outer_diam=3, height=5, position=[5.08,-6.33,-3], rotation=[0,0,0], pitch=0.5, tolerance=0.4) children();
// ScrewHole(outer_diam=3, height=5, position=[-5.08,-6.33,-3], rotation=[0,0,0], pitch=0.5, tolerance=0.4) children();
}

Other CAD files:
stls/Ender5/Ender5MountV8.stl
stls/Fan Mounts/5015_LeftP1.5V4.stl
stls/FlashForgeCreator-Qidi/FanMount.stl
stls/Mount Adapters/18mmInductive.stl
CAD/Building_Blocks/CleanDock.stp
CAD/Ender/Ender3MountV8.stp
CAD/Ender/Ender3_Dock_Modular_All_Parts.stp
CAD/Ender/Ender5DockV7.stp
CAD/Ender/Ender5MountV7Alt.stp
CAD/Ender/Ender_Spacer_Handwheels.stp
CAD/MountAdapters/BLTouch-M2.5ScrewHoles.stp
CAD/MountAdapters/BLTouch-M3HeatSerts.stp
CAD/MountAdapters/BLTouchV3.stp
CAD/MountAdapters/OmronFotekV3.stp
CAD/PROBE-BOARD.step
CAD/PROBE-BOARD_Bot.step
CAD/RailCore/RC_Corner1515_DockMountV4.stp
CAD/RailCore/RailCoreDockTopMountV3.stp
CAD/RailCore/RailCoreDockTopMount_DockV3.stp
CAD/RailCore/RailCoreMountMRW_SD_MountV4.stp
CAD/RailCore/RailcoreMount713Native.stp
CAD/Rat-Rig V-Core/EuclidDockVCore3_3030_V5.stp
CAD/Rat-Rig V-Core/VCoreProDockMount2040.stp
CAD/Rat-Rig V-Core/VCoreProDock_2040.stp
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

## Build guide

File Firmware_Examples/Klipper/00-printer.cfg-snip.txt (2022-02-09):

...
# ad this include statement at the head of the config file
[include euclid.cfg]
#
...

...
# enable enable_force_move to enable FORCE_MOVE and SET_KINEMATIC_POSIITION
```
[force_move]
#enable_force_move: False
#   Set to true to enable FORCE_MOVE and SET_KINEMATIC_POSITION
#   extended G-Code commands. The default is false.
```  

# enable enable response to get feedback from some QGL macros
```
[respond]
#default_type: echo
#   Sets the default prefix of the "M118" and "RESPOND" output to one
#   of the following:
#       echo: "echo: " (This is the default)
#       command: "// "
#       error: "!! "
#default_prefix: echo:
#   Directly sets the default prefix. If present, this value will
#   override the "default_type".
```   

```
[probe]
##    Euclid Probe definitions are also give in the euclid.cfg example file. its user preference as to where to place the information. 
pin: ^PA0                    ; use pin PA0 and enable internal pullup resistor as this is an NC switch  use ! to invert if needed
x_offset: 0                  ; probe is offset 0mm from nozzle
y_offset: 25.0               ; probe is +25mm from nozzle in Y direction
z_offset: 9.5                ; trigger point is 9.5mm below nozzle. larger numbers move effective Z0 CLOSER to the nozzle
speed: 5                     ; probing speed of 5mm/second ideal is <10mm/sec  
samples: 2                   ; number of probes to perform per sample
samples_result: average      ; normalization method: see config reference
sample_retract_dist: 3.0
samples_tolerance: 0.0075
samples_tolerance_retries: 3

#
# example homing overide to use Euclid as an endstop and Z-probe
# example assumes that the bed is 300x300
# assumes homing Z at center of bed
# assumes that macro for probe deploy and retract are M401 and M402
#
[homing_override]
gcode: SET_KINEMATIC_POSITION Z=0
 G0 Z10 F500           ; raise bed to 10
 G28 X Y               ; home Y & Y
 M401                  ; deploy Euclid Probe
 G0 X150 Y150 F12000   ; move to X150 Y150
 G28 Z                 ; home Z
 G0 Z10 F500           ; raise bed to 10
 M402                  ; retract Euclid Probe
axes: z
set_position_z: -5

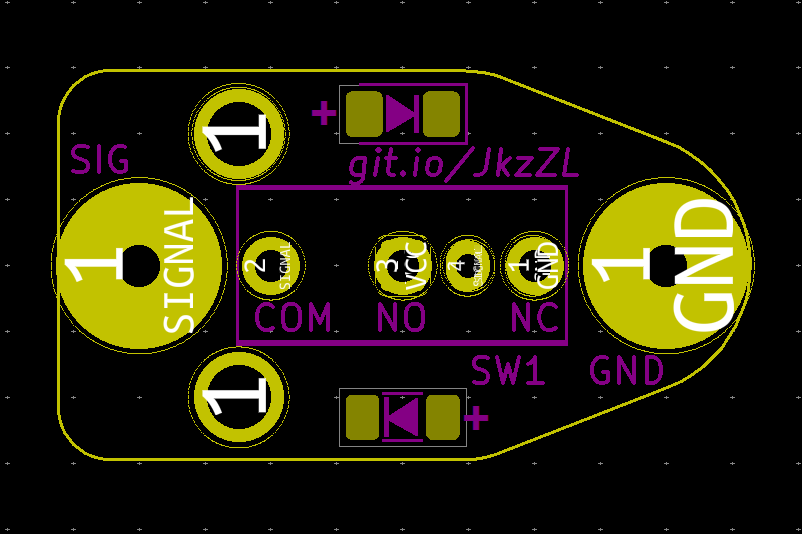
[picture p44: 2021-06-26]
images/SolderMaskBtm.png

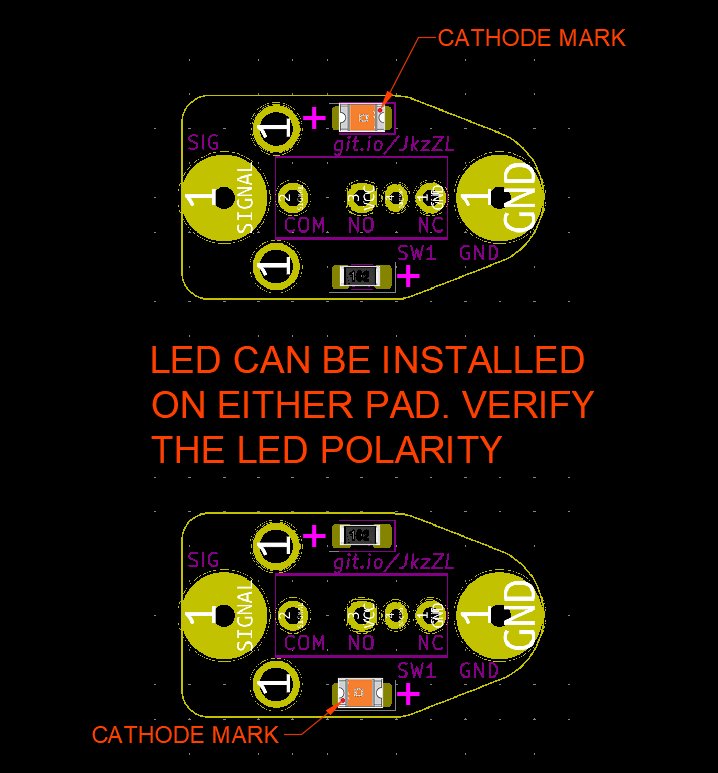
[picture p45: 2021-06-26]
images/LED_Install.png

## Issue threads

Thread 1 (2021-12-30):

failed bed mesh causes probe to crash

shawnp30, 2021-12-30:
hello all. i have a blvcube 500x500 i have my euclid probe set up correctly. it stowes and deploys like it should except when my mesh fails before a print. the probe stays in the last position it was in, when i home the probe is still attached and collides with its dock. what do i need to do in order for my probe to remesh/ redock/ or stay connected and just rehome xyz and mesh again without having to use m401 and m402
[Probe.zip](https://github.com/nionio6915/Euclid_Probe/files/7794927/Probe.zip)
[Euclid (2).zip](https://github.com/nionio6915/Euclid_Probe/files/7794928/Euclid.2.zip)

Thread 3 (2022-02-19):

Voron CAD models missing body.

GiulianoM, 2022-02-19:
The Voron 2.4 mount files under /CAD/Voron are missing the actual body for the mount.

All that are in the files are the extrusions and screws.

Please re-upload the files with the mount bodies included.

nionio6915, 2022-02-19:
i will look and regenerate.
thanks for letting me know

nionio6915, 2022-02-25:
I uploaded all the parts in 1 file as dxf.
You should be able to import into any CAD program.

Closed 2022-02-25.

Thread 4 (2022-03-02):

Supply STEP files

adsaxton, 2022-03-02:
I'm trying to customize mounting, but your STLs won't convert to solid well. Would it be possible to supply STEP files as well? I'd be happy to share my results with you.

nionio6915, 2022-03-03:
There are a bunch of .stp's in the CAD folder.

Which ones do you you need if they are not there?

Fastest way to figure it out would be on discord, jump on over there.

adsaxton, 2022-03-03:
Thanks. I have since found them. I would like the stp of the M3 variant of the BLTouch mount.

Closed 2022-03-03.

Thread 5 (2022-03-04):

Which gantry mount (Voron 2.4) is recommended?

alexvonsiebenthal, 2022-03-04:
I want to replace my Voron's Z endstop pin with the euclid probe. I suppose, I'll need to mount the dock to the gantry - is that correct?
If so, which of the numerous gantry mounts is the one recommended by the Euclid team?

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

Thank you!

nionio6915, 2022-03-05:
The dock can live either on the bedrail or the gantry. Recommend leaving the Z-endstop and use the bed rail dock mount.

If gantry, its dependant on which orientation you want the probe to 'point'  and your firmware macros.
If you are wanting to maitain the klicky macros, use the straight arm.
If you want more secure- use the 90 degree mount.

We just updated the Voron pages in attempt to clarify more.
https://euclidprobe.github.io/02c_Voron.html

Discord discussion is always the fasted response.

Closed 2022-03-05.

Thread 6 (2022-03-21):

homexy.g

bilsch, 2022-03-21:
Hey mind sharing your homexy too?

nionio6915, 2022-03-22:
sure what part?
; ***********************************************************
; homexy.g
; ***********************************************************
;
if boards[0].vIn.current < 23
    M291 S2 R"Turn on power?" P"Power is OFF?"
    M292 P0
    M80
    G4 P1000                           ; wait 1 second for power to stabilize
elif boards[0].vIn.current > 23
   M561                                 ; clear any bed transform
   M290 S0 R0                           ; clear baby steps
   M564 S0 H0                           ; allow movement outside limits
                                        ; Home X and Y at the high end of the axis
   G91                                  ; relative positioning
   G1 H2 Z5 F6000                       ; lift Z relative to current position
   G1 H1 X292 Y325 F9000                ; move quickly to X and Y axis endstops and stop there (first pass)
   G1 H2 X-5 Y-5   F9000                ; go back a few mm
   G1 H1 X292 Y325 F360                 ; move slowly to X and Y axis endstops once more (second pass)
   G1 H2 Z-5 F600                       ; lift Z relative to current position
   G90                                  ; absolute positioning
   M564 S1

nionio6915, 2022-03-22:
i tihnk you want this one too -
```
; ***********************************************************
; homeall.g
; ***********************************************************
; called to home all axes
M98 P"0:/sys/homexy.g"                         ; home x y
M98 P"0:/sys/homez.g"                           ; home z by calling submacros

```

bilsch, 2022-03-22:
you rock thanks!

bilsch, 2022-03-22:
oh, so boards[0] is the duet board right? Then we can index into other boards if we want? say I have a/b on the 3hc and its board 1 - boards[1]... would get that detail for the other board right?

nionio6915, 2022-03-22:
I do not know the Duet3x hardware at all.

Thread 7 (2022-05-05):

Config for Klipper 00-euclid_exampleV4.cfg can't be parsed by clipper

VTopoliuk, 2022-05-05:
Klipper version: v0.10.0-387
Error:
```
Error loading template 'gcode_macro DEPLOY_PROBE:gcode': TemplateSyntaxError: expected token 'end of print statement', got 'DOCK'
```
Happens without any modification to original file

nionio6915, 2022-06-05:
can you provide your printer.cfg and the macro file you are using?

arikhris, 2022-06-05:
`# array variables implementation and
# macro setups credited to user yolodubstep
# see  https://github.com/blalor/vcore3-ratos-config
# for updates and details
#  __________________________________________________________________________
#  |                                                                        |
#  |                                                                        |
#  |                                                                        |
#  |                                                                        |
#  |                                                                        |
#  |                                                                        |
#  |                                                                        |
#  |                                                                        |
#  |                                                                        |
#  |                                                                        |
#  |                                * Probe Ready Position                  |
#  |                                  X150 Y150                             |
#  |                                                                        |
#  |                                                                        |
#  | * Dock Re-entry staging  position                                      |
#  |   X0 Y70                                                               |
#  |                                                                        |
#  |                                                                        |
#  | * Dock Exit Position                                                   |
#  |   X0 Y40                                                               |
#  |                                                                        |
#  |                                                                        |
#  |                                                                        |
#  |                                                                        |
#  |                                                                        |
#  |   X0 Y0    X30 Y0       X100 Y0                                        |
#  | * Dock   * Dock Side  * Dock Preflight                                 |
#  |________________________________________________________________________|
#
# Above is example 300x300 bed to coorelate with macros and movements below.
# This example is for a fixed dock, fixed gantry/carraige and moving bed motion
# system like RailCore, Ender5, V-Core3, etc...
# Delta printes will be similar
# Moving gantry printers like Voron need a a few tweaks to ensure clearances
#  - see cpmments in the code

[gcode_macro EuclidProbe]
description: config vars for Euclid probe deploy/stow

## Replace the cordinates to suit your printer for deployment steps
variable_position_preflight: [ 100, 348 ] # positions for probe to have clear path to dock
variable_position_side:      [  30, 348 ] # position for probe near dock to swipe on
variable_position_dock:      [   0, 348 ] # dock position
## exit/re-entry staging
variable_position_exit:      [   0, 40 ] # exit position

## how much space to put between the bed and nozzle for homing
# RatOS
variable_bed_clearance: 15

# 300 * 60
variable_move_speeds: 18000

variable_batch_mode_enabled: False
variable_probe_state: None

gcode:
    RESPOND TYPE=command MSG="{ printer['gcode_macro EuclidProbe'] }"

# the following is a hardware probe config for the hardware configuration.
# it can appear in the printer.cfg or in the euclid.cfg
# USE IT IN ONE LOCATION ONLY

[homing_override]
# homing overide is machine specific. this example os for fixed gantry moving bed printer
# users need to verify application or comment out
axes: z
set_position_z: -5
gcode:
    {% set euclid_probe = printer["gcode_macro EuclidProbe"] %}

    G90

    ;; force bed to move 15mm
    SET_KINEMATIC_POSITION Z=0
    G0 Z{ euclid_probe.bed_clearance } F500

    ;; home Y and X, Y first to avoid running into the dock
    {% if "y" not in (printer.toolhead.homed_axes | lower) %}
        G28 Y
    {% endif %}

    {% if "x" not in (printer.toolhead.homed_axes | lower) %}
        G28 X
    {% endif %}

    DEPLOY_PROBE

    ;; home Z at bed center
    G0 X{ printer.toolhead.axis_maximum.x/2 } Y{ printer.toolhead.axis_maximum.y/2 } F{ euclid_probe.move_speeds }
    G28 Z

    ;; after 'G28 Z' the probe stays in contact with the bed; move it away.
    G0 Z{ euclid_probe.bed_clearance }

    STOW_PROBE

[gcode_macro _ASSERT_PROBE_STATE]
description: ensures probe is in a known state; QUERY_PROBE must have been called before this macro!
gcode:
    ## QUERY_PROBE manually-verified results, when microswitch not depressed
    ## "TRIGGERED" -> 1 :: probe stowed
    ## "open"      -> 0 :: probe deployed
    {% set last_query_state = "stowed" if printer.probe.last_query == 1 else "deployed" %}

    {% if params.MUST_BE != last_query_state %}
        { action_raise_error("expected probe state to be {} but is {} ({})".format(params.MUST_BE, last_query_state, printer.probe.last_query)) }
    {% else %}
        ## all good; update state
        SET_GCODE_VARIABLE MACRO=EuclidProbe VARIABLE=probe_state VALUE="'{ last_query_state }'"
    {% endif %}

[gcode_macro ASSERT_PROBE_DEPLOYED]
description: error if probe not deployed
gcode:
    ; wait for moves to finish, then pause 0.25s for detection
    M400
    G4 P250

    QUERY_PROBE
    _ASSERT_PROBE_STATE MUST_BE=deployed

[gcode_macro ASSERT_PROBE_STOWED]
description: error if probe not stowed
gcode:
    ; wait for moves to finish, then pause 0.25s for detection
    M400
    G4 P250

    QUERY_PROBE
    _ASSERT_PROBE_STATE MUST_BE=stowed

[gcode_macro EUCLID_PROBE_BEGIN_BATCH]
description: begin euclid probe batch mode
gcode:
    SET_GCODE_VARIABLE MACRO=EuclidProbe VARIABLE=batch_mode_enabled VALUE=True
    RESPOND TYPE=command MSG="Probe batch mode enabled"

[gcode_macro EUCLID_PROBE_END_BATCH]
description: end euclid probe batch mode and stow probe
gcode:
    SET_GCODE_VARIABLE MACRO=EuclidProbe VARIABLE=batch_mode_enabled VALUE=False
    RESPOND TYPE=command MSG="Probe batch mode disabled"
    STOW_PROBE

[gcode_macro DEPLOY_PROBE]
description: deploy Euclid probe
gcode:
    {% set euclid_probe = printer["gcode_macro EuclidProbe"] %}

    {% if euclid_probe.batch_mode_enabled and euclid_probe.probe_state == "deployed" %}
        RESPOND TYPE=command MSG="Probe batch mode enabled: already deployed"
    {% else %}
        RESPOND TYPE=command MSG="Deploying probe"

        ; ensure the probe is currently stowed; can't deploy what isn't stowed.
        ASSERT_PROBE_STOWED

        G90

        ; set approach elevation to clear probe over bed on fixed gantry machine
        G0 Z{ euclid_probe.bed_clearance } F500

        ; move the carraige to safe position to start probe pickup
        G0 X{ euclid_probe.position_preflight[0] } Y{ euclid_probe.position_preflight[1] } F{ euclid_probe.move_speeds }

        ;  move to the side of the dock
        G0 X{ euclid_probe.position_side[0] } Y{ euclid_probe.position_side[1] } F{ euclid_probe.move_speeds }

        ; fixed bed dock and moving gantry printers need to add a move command here to lower the gantry to dock height
        ; G0 Z{INSERT DOCK HEIGHT} F500

        ; wait 1/4 second
        M400
        G4 P250

        ;  move sideways over the dock to pick up probe
        G0 X{ euclid_probe.position_dock[0] } Y{ euclid_probe.position_dock[1] } F1500

        ; confirm deploy was successful
        ASSERT_PROBE_DEPLOYED

        ; move out of the dock in a straight line
        G0 X{ euclid_probe.position_exit[0] } Y{ euclid_probe.position_exit[1] } F{ euclid_probe.move_speeds }
    {% endif %}

[gcode_macro STOW_PROBE]
description: stow Euclid probe
gcode:
    {% set euclid_probe = printer["gcode_macro EuclidProbe"] %}

    {% if euclid_probe.batch_mode_enabled %}
        RESPOND TYPE=command MSG="Probe batch mode enabled: not stowing"
    {% else %}
        RESPOND TYPE=command MSG="Stowing probe"

        ; ensure the probe is currently deployed; can't stow what isn't deployed.
        ASSERT_PROBE_DEPLOYED

        G90

        ; set approach elevation for fixed gantry system to clear probe over bed
        G0 Z{ euclid_probe.bed_clearance } F3000

        ; fixed bed dock and moving gantry printers need to add a move command here to lower the gantry to dock height
        ; G0 Z{INSERT DOCK HEIGHT} F500

        ; move to the exit/re-entry staging position
        G0 X{ euclid_probe.position_exit[0] } Y{ euclid_probe.position_exit[1] } F{ euclid_probe.move_speeds }

        ; slowly move into dock
        G0 X{ euclid_probe.position_dock[0] } Y{ euclid_probe.position_dock[1] } F3000

        ; wait for moves to finish, pause to force 90deg travel swipe
        M400
        G4 P250

        ; quick swipe off
        G0 X{ euclid_probe.position_side[0] } Y{ euclid_probe.position_side[1] } F{ euclid_probe.move_speeds }

        ; confirm stowing was successful
        ASSERT_PROBE_STOWED
    {% endif %}

; # Example macro to perform a bed mesh calibration by wrapping it in DEPLOY_PROBE/STOW_PROBE macros
[gcode_macro BED_MESH_CALIBRATE]
rename_existing: BED_MESH_CALIBRATE_ORIG
gcode:
    DEPLOY_PROBE
    BED_MESH_CALIBRATE_ORIG
    STOW_PROBE

[gcode_macro START_PRINT]
# call from slicer priner gcode via
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
arikhris, 2022-06-05:
same errror as op

nionio6915, 2022-06-06:
please upload your printer.cfg and your klipper/moonraker versions

nionio6915, 2022-06-07:
OK, we think we have a handle on this.

Lines 189-190 are comments to provide users instructions to add a move command to clear the dock height on moves. I beleive that klipper is parsing over the comment and trying to evaluate whats inside the brackets.

```
; fixed bed dock and moving gantry printers need to add a move command here to lower the gantry to dock height
; G0 Z{INSERT DOCK HEIGHT} F500
```

Could you to try the following-

1. After line 55 add a comment and a variable
```
# dock clearance height for docking and stow macros
variable_dock_height: 15
```

2. Revise line 190 to
```; G0 Z {euclid_probe.dock_height} F500```

I believe that this will elimintate the error.  I ask that you try it because my klipper machines are not gantries.

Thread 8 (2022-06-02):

soldering_jigV5-0.2mm_margin.stl has broken vertices on top layer

martinw89, 2022-06-02:
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

There appears to be some broken vertices in the current 0.2mm version of the jig. These are not present on the 0.3mm version. Visible in the github STL previewer, so I don't think it's a local problem with my slicer

nionio6915, 2022-06-05:
thanks for letting us know.
we fixed them in the 0.2mm and checked/fixed the rest too.

Closed 2022-06-05.

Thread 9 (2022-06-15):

All CAD Files in Voron Directory are compromised

Markus-1984, 2022-06-15:
Hi @all,

unfortuanly all the CAD files in the Voron Directory are not usable.
Please reupload this files.

Best regards
Markus

nionio6915, 2022-06-17:
can you please be more specific in your critiscism?

nionio6915, 2022-06-17:
can you please be more specific in your critiscism? which one is the issue?

Closed 2022-06-17.

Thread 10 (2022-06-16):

Small errors to fix

adamfilip, 2022-06-16:
RRF3_Example_Auto_Deploy_Probe_Fixed_Dock.g

Line 104
G0 X150 Y150 G3000            ; move to the center of the bed

G3000 should be F3000

---------------------------------
RRF3_Example_Auto_Retract_Probe_Fixed_Dock.g

Line 68
G0 X0 Y70 F3000               ; move to ready position

Should be updated to be

G0 X0 Y70 F3000               ; move to Dock Re-entry staging  position

nionio6915, 2022-06-17:
thank you.

Closed 2022-07-05.

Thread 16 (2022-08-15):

Bug in 00-euclid_exampleV5.cfg crashes Bed into Hotend

MartinGiersberg, 2022-08-15:
When using the Euclide probe on a V-Core 3 - 400 Machine while running RatOS and having a Z-Offset >=+5mm the Code in the line 136 of "00-euclid_exampleV5.cfg", G0 Z5, will make the Bed move in the wron direction after homing Z. If the Z-Offset is <5mm this wont happen and the bed will move as expected after homing.

FIX: Change the value for Z in the line 136 so that is is always strictly larger than your Z-Offset

nionio6915, 2022-08-15:
thank your for catching this. There should have been a G91 before this. after some consideration, it has been revised to be the bed_clearance value.

    # after 'G28 Z' the probe stays in contact with the bed; move it away bed_clearance height.
    G0 Z{euclid_probe.bed_clearance} F500

MartinGiersberg, 2022-08-16:
I tested this code on my machine and it works like a charm. Thanks a lot!

Closed 2022-08-15.

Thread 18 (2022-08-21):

http://www.example.com/report”:  http://www.example.com/report"><href="RFC6761/a></https://www.icann.org/en=Th_TH /public-comment/proceeding/root-zone-label-generation-rules-version-5-rz-lgr-5-24-03-2022-  (“<p>”)  "moreinfo" CSS:class="moreinfo"> RFC6761  p.moreinfo { http:// www.example.com www.example.com/report”:  <p class="moreinfo"> <a href="http://www.example.com/report">issues</a></p> class has (“<p>”) "moreinfo"  CSS:p.moreinfo {RFC6761}  HTMRZ-LGR RZ-LGR-5L  - h-j-p

prindawigidgindawong, 2022-08-21:
[https://www.amazon.com/gp/product/B07PVTBWX7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](Google.pam.ms )

bryanboettcher, 2022-12-18:
nothing of value here at all, delete.

Closed 2023-08-14.

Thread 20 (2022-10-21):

The Probe Is Already Attached - But it isn't

JohnGalt1717, 2022-10-21:
Hi, I have setup everything and verified it's in NC mode and checking the pin shows that it's low, but the default M401 script is telling me that the probe is already attached when it isn't.

Fortunately QGL then fails because it recognizes it isn't there.

Here's the PROBE section in Klipper:
```

[probe]
pin: ^EBBCan: PB5
x_offset: 5
y_offset: -20
z_offset: 5.379
speed: 5
samples: 2
samples_result: average
sample_retract_dist: 3.0
samples_tolerance: 0.050
samples_tolerance_retries: 3
lift_speed: 30
```

Interestingly, after the message from the 401 comes up on the console, if you click it immediately again, it's correct and goes and gets the probe.

nionio6915, 2022-10-23:
the probe status is cached. You need to query it before you need it.
try putting QUERY_PROBE in your startup script.

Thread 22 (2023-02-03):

Probe deploys instead of batch mode

shawnp30, 2023-02-03:
[klippy (3).log](https://github.com/nionio6915/Euclid_Probe/files/10574615/klippy.3.log)
[Euclid (8).zip](https://github.com/nionio6915/Euclid_Probe/files/10574626/Euclid.8.zip)
[print_area_bed_mesh (5).zip](https://github.com/nionio6915/Euclid_Probe/files/10574632/print_area_bed_mesh.5.zip)
hello i am using euclid probe with blvcube printer 500x500 build. i am having issues with the latest euclid commands. when using print bed mesh calibrate by turge08 stuff gets weird. assert probe command for me do not work. i get error probes already triggered. When the gcode does work I can home the bed and z tilt adjust. the probe is supposed to stow but it doesnt, the probe goes to the left of the dock and swipes it off causing an error saying probe already triggered. what do i need to change in order for this macro to work?

Closed 2023-02-09.

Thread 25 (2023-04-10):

Provided M2.5 self-tapping screws *will* split Clockwork2_Euclid_MGN12X_RIGHT_Carriage_Ver2.stl

docpayce, 2023-04-10:
On the main Voron installation guide:
https://euclidprobe.github.io/02c_Voron2.html#clockwork2--stealthburner-native-mounts

it is mentioned under section "Clockwork2 & Stealthburner Native Mounts" that

> The left and right halves of the native carriage shells for Voron Stealthburner / CW2 / Clockwork 2 have been modified to accept the probe **with M2.5 self tapping screws** from underneath.

Though the provided screws in the kit are to long to fit and will split the printed part "Clockwork2_Euclid_MGN12X_RIGHT_Carriage_Ver2.stl"  ([Link](https://github.com/nionio6915/Euclid_Probe/blob/main/stls/Voron/Clockwork2_Euclid_MGN12X_RIGHT_Carriage_Ver2.stl)) open rendering it unusable.

I would strongly suggest to implement the mounting holes either deeper or as full thru-holes instead of pocket holes. As an alternative, heatset inserts may be a more viable solution, too, certainly preventing splitting the printed part in that kind of delicate area.

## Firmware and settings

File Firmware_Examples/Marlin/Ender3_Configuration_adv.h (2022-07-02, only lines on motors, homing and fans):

#define E0_AUTO_FAN_PIN -1
#define E1_AUTO_FAN_PIN -1
#define E2_AUTO_FAN_PIN -1
#define E3_AUTO_FAN_PIN -1
#define E4_AUTO_FAN_PIN -1
#define E5_AUTO_FAN_PIN -1
#define E6_AUTO_FAN_PIN -1
#define E7_AUTO_FAN_PIN -1
#define CHAMBER_AUTO_FAN_PIN -1
#define COOLER_AUTO_FAN_PIN -1
#define COOLER_FAN_PIN -1
#define HOMING_BUMP_MM      { 5, 5, 2 }       // (mm) Backoff from endstops after first bump
#define HOMING_BUMP_DIVISOR { 2, 2, 4 }       // Re-Bump Speed Divisor (Divides the Homing Feedrate)
#define MICROSTEP_MODES { 16, 16, 16, 16, 16, 16 } // [1,2,4,8,16]
#define ADVANCED_PAUSE_FEATURE
  #define ADVANCED_PAUSE_PURGE_FEEDRATE       6   // (mm/s) Extrude feedrate (after loading). Should be slower than load feedrate.
  #define ADVANCED_PAUSE_PURGE_LENGTH         25  // (mm) Length to extrude after loading.
  #define ADVANCED_PAUSE_RESUME_PRIME          5  // (mm) Extra distance to prime nozzle after returning from park.

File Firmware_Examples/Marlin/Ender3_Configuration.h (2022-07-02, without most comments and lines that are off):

#pragma once
#define CONFIG_EXAMPLES_DIR "Creality/Ender-3 Pro/CrealityV422"
#define CONFIGURATION_H_VERSION 02000901
#define STRING_CONFIG_H_AUTHOR "(djp, Ender3Euclid)" // Who made the changes.
#define SHOW_BOOTSCREEN
#define SHOW_CUSTOM_BOOTSCREEN
#define CUSTOM_STATUS_SCREEN_IMAGE
#define SERIAL_PORT 1
#define BAUDRATE 115200
#define SERIAL_PORT_2 3
  #define MOTHERBOARD BOARD_CREALITY_V4
#define CUSTOM_MACHINE_NAME "E3Pro V070222f" //DJP EDIT
#define MACHINE_UUID "cede2a2f-41a2-4748-9b12-c55c62f367ff"
#if LINEAR_AXES >= 4
  #define AXIS4_NAME 'A' // :['A', 'B', 'C', 'U', 'V', 'W']
#endif
#if LINEAR_AXES >= 5
  #define AXIS5_NAME 'B' // :['A', 'B', 'C', 'U', 'V', 'W']
#endif
#if LINEAR_AXES >= 6
  #define AXIS6_NAME 'C' // :['A', 'B', 'C', 'U', 'V', 'W']
#endif
#define EXTRUDERS 1
#define DEFAULT_NOMINAL_FILAMENT_DIA 1.75
#define TEMP_SENSOR_0 1
#define TEMP_SENSOR_1 0
#define TEMP_SENSOR_2 0
#define TEMP_SENSOR_3 0
#define TEMP_SENSOR_4 0
#define TEMP_SENSOR_5 0
#define TEMP_SENSOR_6 0
#define TEMP_SENSOR_7 0
#define TEMP_SENSOR_BED 1
#define TEMP_SENSOR_PROBE 0
#define TEMP_SENSOR_CHAMBER 0
#define TEMP_SENSOR_COOLER 0
#define TEMP_SENSOR_BOARD 0
#define TEMP_SENSOR_REDUNDANT 0
#define DUMMY_THERMISTOR_998_VALUE  25
#define DUMMY_THERMISTOR_999_VALUE 100
#define TEMP_RESIDENCY_TIME         10  // (seconds) Time to wait for hotend to "settle" in M109
#define TEMP_WINDOW                  1  // (°C) Temperature proximity for the "temperature reached" timer
#define TEMP_HYSTERESIS              3  // (°C) Temperature proximity considered "close enough" to the target
#define TEMP_BED_RESIDENCY_TIME     10  // (seconds) Time to wait for bed to "settle" in M190
#define TEMP_BED_WINDOW              1  // (°C) Temperature proximity for the "temperature reached" timer
#define TEMP_BED_HYSTERESIS          3  // (°C) Temperature proximity considered "close enough" to the target
#define TEMP_CHAMBER_RESIDENCY_TIME 10  // (seconds) Time to wait for chamber to "settle" in M191
#define TEMP_CHAMBER_WINDOW          1  // (°C) Temperature proximity for the "temperature reached" timer
#define TEMP_CHAMBER_HYSTERESIS      3  // (°C) Temperature proximity considered "close enough" to the target
#if TEMP_SENSOR_REDUNDANT
  #define TEMP_SENSOR_REDUNDANT_SOURCE    E1  // The sensor that will provide the redundant reading.
  #define TEMP_SENSOR_REDUNDANT_TARGET    E0  // The sensor that we are providing a redundant reading for.
  #define TEMP_SENSOR_REDUNDANT_MAX_DIFF  10  // (°C) Temperature difference that will trigger a print abort.
#endif
#define HEATER_0_MINTEMP   0
#define HEATER_1_MINTEMP   5
#define HEATER_2_MINTEMP   5
#define HEATER_3_MINTEMP   5
#define HEATER_4_MINTEMP   5
#define HEATER_5_MINTEMP   5
#define HEATER_6_MINTEMP   5
#define HEATER_7_MINTEMP   5
#define BED_MINTEMP        0
#define CHAMBER_MINTEMP    5
#define HEATER_0_MAXTEMP 275
#define HEATER_1_MAXTEMP 275
#define HEATER_2_MAXTEMP 275
#define HEATER_3_MAXTEMP 275
#define HEATER_4_MAXTEMP 275
#define HEATER_5_MAXTEMP 275
#define HEATER_6_MAXTEMP 275
#define HEATER_7_MAXTEMP 275
#define BED_MAXTEMP      120
#define CHAMBER_MAXTEMP  60
#define HOTEND_OVERSHOOT 15   // (°C) Forbid temperatures over MAXTEMP - OVERSHOOT
#define BED_OVERSHOOT    10   // (°C) Forbid temperatures over MAXTEMP - OVERSHOOT
#define COOLER_OVERSHOOT  2   // (°C) Forbid temperatures closer than OVERSHOOT
#define PIDTEMP
#define BANG_MAX 255     // Limits current to nozzle while in bang-bang mode; 255=full current
#define PID_MAX BANG_MAX // Limits current to nozzle while PID is active (see PID_FUNCTIONAL_RANGE below); 255=full current
#define PID_K1 0.95      // Smoothing factor within any PID loop
    #define DEFAULT_Kp  28.72
    #define DEFAULT_Ki   2.62
    #define DEFAULT_Kd  78.81
#define PIDTEMPBED
#define MAX_BED_POWER 255 // limits duty cycle to bed; 255=full current
  #define DEFAULT_bedKp 462.10
  #define DEFAULT_bedKi 85.47
  #define DEFAULT_bedKd 624.59
#define MAX_CHAMBER_POWER 255 // limits duty cycle to chamber heater; 255=full current
  #define PID_FUNCTIONAL_RANGE 10 // If the temperature difference between the target temperature and the actual temperature
#define PREVENT_COLD_EXTRUSION
#define EXTRUDE_MINTEMP 180
#define PREVENT_LENGTHY_EXTRUDE
#define EXTRUDE_MAXLENGTH 1000
#define THERMAL_PROTECTION_HOTENDS // Enable thermal protection for all extruders
#define THERMAL_PROTECTION_BED     // Enable thermal protection for the heated bed
#define THERMAL_PROTECTION_COOLER  // Enable thermal protection for the laser cooling
#define USE_XMIN_PLUG
#define USE_YMIN_PLUG
#define USE_ZMAX_PLUG
#define ENDSTOPPULLUPS
#define X_MIN_ENDSTOP_INVERTING false // Set to true to invert the logic of the endstop.
#define Y_MIN_ENDSTOP_INVERTING false // Set to true to invert the logic of the endstop.
#define Z_MIN_ENDSTOP_INVERTING false // Set to true to invert the logic of the endstop.
#define I_MIN_ENDSTOP_INVERTING false // Set to true to invert the logic of the endstop.
#define J_MIN_ENDSTOP_INVERTING false // Set to true to invert the logic of the endstop.
#define K_MIN_ENDSTOP_INVERTING false // Set to true to invert the logic of the endstop.
#define X_MAX_ENDSTOP_INVERTING false // Set to true to invert the logic of the endstop.
#define Y_MAX_ENDSTOP_INVERTING false // Set to true to invert the logic of the endstop.
#define Z_MAX_ENDSTOP_INVERTING false // Set to true to invert the logic of the endstop.
#define I_MAX_ENDSTOP_INVERTING false // Set to true to invert the logic of the endstop.
#define J_MAX_ENDSTOP_INVERTING false // Set to true to invert the logic of the endstop.
#define K_MAX_ENDSTOP_INVERTING false // Set to true to invert the logic of the endstop.
#define Z_MIN_PROBE_ENDSTOP_INVERTING false // Set to true to invert the logic of the probe.
#define X_DRIVER_TYPE A4988  // DJP EDIT VERIFIED BOARD IS 4.2.2 NOISY A4988
#define Y_DRIVER_TYPE A4988
#define Z_DRIVER_TYPE A4988
#define E0_DRIVER_TYPE A4988
#define ENDSTOP_INTERRUPTS_FEATURE
#define DEFAULT_AXIS_STEPS_PER_UNIT   { 80, 80, 400, 93 }
#define DEFAULT_MAX_FEEDRATE          { 200, 200, 100, 100 }
#define LIMITED_MAX_FR_EDITING        // Limit edit via M203 or LCD to DEFAULT_MAX_FEEDRATE * 2
  #define MAX_FEEDRATE_EDIT_VALUES    { 600, 600, 150, 150 } // ...or, set your own edit limits
#define DEFAULT_MAX_ACCELERATION      { 500, 500, 100, 1000 }
#define DEFAULT_ACCELERATION          500    // X, Y, Z and E acceleration for printing moves
#define DEFAULT_RETRACT_ACCELERATION  500    // E acceleration for retracts
#define DEFAULT_TRAVEL_ACCELERATION   1000    // X, Y, Z acceleration for travel (non printing) moves
#define CLASSIC_JERK
  #define DEFAULT_XJERK 10.0
  #define DEFAULT_YJERK 10.0
  #define DEFAULT_ZJERK  0.3
#define DEFAULT_EJERK    5.0  // May be used by Linear Advance
#define S_CURVE_ACCELERATION  //DJP EDIT ENABLE
#define Z_MAX_PIN PA7 // DJP EDIT ADD
#define Z_MIN_PROBE_PIN   PB1 // This is the I/O pin used for the BLTouch sensor
#define Z_PROBE_ALLEN_KEY
  #define Z_PROBE_ALLEN_KEY_DEPLOY_1 { 55, 30, 10 }    // ENDER3 MOVE TO DOCK SIDE ADJACENT
  #define Z_PROBE_ALLEN_KEY_DEPLOY_1_FEEDRATE (XY_PROBE_FEEDRATE)*1
  #define Z_PROBE_ALLEN_KEY_DEPLOY_2 { 55, 0, 0 }    //  ENDER3 MOVE DOWN TO COUPLE PROBE
  #define Z_PROBE_ALLEN_KEY_DEPLOY_2_FEEDRATE (XY_PROBE_FEEDRATE)*1
  #define Z_PROBE_ALLEN_KEY_DEPLOY_3 { 20, 0, 0 }    //  ENDER3 MOVE PROBE OUT OF DOC
  #define Z_PROBE_ALLEN_KEY_DEPLOY_3_FEEDRATE (XY_PROBE_FEEDRATE)/4
  #define Z_PROBE_ALLEN_KEY_DEPLOY_4 { 20, 0, 15.0 }  // ENDER3 RAISE PROBE ABOVE DOCK SLOWLY
  #define Z_PROBE_ALLEN_KEY_DEPLOY_4_FEEDRATE (XY_PROBE_FEEDRATE)/4
  #define Z_PROBE_ALLEN_KEY_STOW_1 { 25, 0, 0.0 }    // ENDER3 MOVE THE PROBE TO THE XY READY POSITION
  #define Z_PROBE_ALLEN_KEY_STOW_1_FEEDRATE (XY_PROBE_FEEDRATE)*1
  #define Z_PROBE_ALLEN_KEY_STOW_2 { 100, 0, 0.0 }     // ENDER3 LOWER PROBE TO DOCK ENTRY ELEVATION
  #define Z_PROBE_ALLEN_KEY_STOW_2_FEEDRATE (XY_PROBE_FEEDRATE)*3
  #define Z_PROBE_ALLEN_KEY_STOW_3 { 100, 0, 20.0 }     // ENDER3 STOW PROBE AND SWIPE OFF
  #define Z_PROBE_ALLEN_KEY_STOW_3_FEEDRATE (XY_PROBE_FEEDRATE)*3
  #define Z_PROBE_ALLEN_KEY_STOW_4 { 118, 118, 20.0 }     // ENDER3 STOW PROBE AND SWIPE OFF
  #define Z_PROBE_ALLEN_KEY_STOW_3_FEEDRATE (XY_PROBE_FEEDRATE)*3
#define NOZZLE_TO_PROBE_OFFSET { -45.2, -17.5, -10.5 } // LEFT SIDE BED MOUNT
#define PROBING_MARGIN 15
#define XY_PROBE_FEEDRATE (200*60)
#define Z_PROBE_FEEDRATE_FAST (15*60)
#define Z_PROBE_FEEDRATE_SLOW (Z_PROBE_FEEDRATE_FAST / 3)
#define MULTIPLE_PROBING 2
#define EXTRA_PROBING    1
#define Z_CLEARANCE_DEPLOY_PROBE    12 // Z Clearance for Deploy/Stow Was 12 now 9
#define Z_CLEARANCE_BETWEEN_PROBES  12 // Z Clearance between probe points
#define Z_CLEARANCE_MULTI_PROBE     12 // Z Clearance between multiple probes
#define Z_AFTER_PROBING             12 // Z position after probing is done
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

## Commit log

2020-11-20 addd CADs and images
    [PROBE-BOARD.kicad_pcb, probe-dock.dwg, probe-dock.stp]
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2020-11-20 updated gerbers, added XH
    [91290A110_BLACK-OXIDE CLASS 12.9 SOCKET HEAD CAP SCREW.STEP, 94180A333_HEAT-SET INSERTS FOR PLASTICS.STEP, 97763A811_BLACK-OXIDE 18-8 SS BUTTON-HEAD CAP SCREW.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]
2020-11-21 move M3 mounting holes, recreted CAD, added gerbers
    [94459A130_BRASS HEAT-SET INSERT FOR PLASTIC.STEP, BOT-BOARD.dwg, Bottom_Board.stp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]
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2021-07-16 Dock Updates
    Revised RailCore Docks and Mounts
    [91290A110_BLACK-OXIDE CLASS 12.9 SOCKET HEAD CAP SCREW.STEP, 91290A115_BLACK-OXIDE CLASS 12.9 SOCKET HEAD CAP SCREW.STEP, 94180A333_HEAT-SET INSERTS FOR PLASTI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]
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2021-07-23 Create Example_deployprobeManual.g
    Added Manual Probe Deployment macro
    [Example_deployprobeManual.g]
2021-07-26 Voron 2.4 Bed Mount rev2
    [025mag-PROBE-BOARD_REV2-B_Adhes.gbr, 025mag-PROBE-BOARD_REV2-B_CrtYd.gbr, 025mag-PROBE-BOARD_REV2-B_Cu.gbr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]
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2021-09-27 Updated stls for Ender3, Ender5 and Voron
    [Ender3PartsPlateV7.stl, Ender3ProDockModularV3.1.stl, Ender3ProDockMountV3.stl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]
2021-09-30 Updated docks & Mounts
    Updated Ende3, Ender5, Omron/Fotek, Voron AfterBurner
    [Ender3DockV3.stl, Ender3MountV7.stl, Ender3MountV7Alternate.stl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]
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2021-11-19 corrected typos in RRF3 files
    [RRF3_Example_Auto_Deploy_Probe_Fixed_Dock.g, RRF3_Example_Auto_Deploy_Probe_MovingZ_Dock.g]
2021-11-21 Corrected RRF2 macro example
    [RRF2_Example_Auto_Deploy_Probe.g]
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2021-12-08 updated stls, klipper macros
    [Ender3DockMountV4.stl, Ender5DockV7.stl, Ender5DockV8.stl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]
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2021-12-11 klipper config examples ad
    [Ender5_euclid 25-9-2021.cfg, RailCore_JohnOCFII_printer-22October2021.cfg, qidi_euclid.cfg]
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2021-12-11 fixed M5 length on Trident Dock
    [Trident_TopMountDockCloseV4.stl]
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2021-12-12 fixed print orientation
    [BLTouchV3-M2Screws.stl]
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2021-12-30 revised bore for screw
    [Euclid_EVA_MountV5_M2.5SelfTapping.stl]
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2022-01-15 updated soldering jigs, added dxf versions
    [TridentMount.dxf, Voron2.4BedMountV3.dxf, Voron2.4BedMount_TallerV3.dxf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]
2022-01-21 Broke apart Gantry mount into 2 stls
    [VoronGantryMount2_Arm.stl, VoronGantryMount2_Bkt.stl]
2022-01-22 Added MGN12 Native Mount, Renamed to Clockwork1 for Voron Dev consistency
    [Clockwork1_2XMGN9_Native_Left.stl, Clockwork1_2XMGN9_Native_Right.stl, Clockwork1_MGN12_Native_Left_Beta.stl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]
2022-01-22 Updated Voron CW1 files
    [Clockwork1_MGN12_Left.stl, Clockwork1_MGN12_Native_Left_Beta.stl, Clockwork1_MGN12_Native_RightM2.5Screw_Beta.stl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]
2022-01-22 RRF Typo fix
    [RRF3_Example_Auto_Deploy_Probe_Fixed_Dock.g]
2022-01-23 Added bedmap to RRF3 deploy macro
    [00-euclid_exampleV2.cfg, RRF3_Example_Auto_Deploy_Probe_Fixed_Dock.g]
2022-01-23 added ascii graphics to RRF files
    [RRF2_Example_Auto_Deploy_Probe.g, RRF2_Example_Auto_Retract_Probe_Fixed_Dock.g, RRF3_Example_Auto_Deploy_Probe_Fixed_Dock.g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]
2022-01-25 V-Core Legacy Dock updated
    [LegacyVCoreDockV2.stl]
2022-01-26 Klipper example revised to V3
    [00-euclid_exampleV3.cfg, CW1_MGN12.dxf, CW1_MGN12.stp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]
2022-01-26 Hyprecube BLT Adapter Added
    [BLTouch4HypercubeHtSrts.stl, BLTouch4HypercubeM3Nuts.stl, Clockwork1_MGN12_LeftM2.5Screw_Strain_Relief.stl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]
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2022-02-07 confirm blocks up to date
    [ProbeV4.dxf, mag-polatiry.dwg]
2022-02-09 fixed RRF typo
    [025mag-PROBE-BOARD_REV2-B_Adhes.gbr, 025mag-PROBE-BOARD_REV2-B_CrtYd.gbr, 025mag-PROBE-BOARD_REV2-B_Cu.gbr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]
2022-02-14 fixed typos rrf macro
    [RRF3_Example_Auto_Deploy_Probe_MovingZ_Dock.g]
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2022-02-22 voron stp files, klipper cfgs
    [TridentMount.stp, Voron2.4BedMount.stp, Voron2.4BedMount_TallerV3.dxf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]
2022-02-27 fixed typos in QGL
    [00-euclid_exampleV3.cfg, 00-euclid_exampleV3_scratch.cfg, Voron2.4_rkolbi.cfg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]
2022-03-04 updates VCore EVA Mount
    [00-euclid_exampleV4.cfg, Clockwork1_2XMGN9_Native_LeftM2.5.3mf, Euclid_EVA_MountV5_M2.5SelfTapping.stl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]
2022-03-06 Voron Bed Mount Updated
    [Voron2.4BedMount_TallerV3.iges, Voron2.4BedMount_TallerV3.stp, Voron_All-Dock_Parts.dxf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]
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2022-03-06 Added Omron Mount Adapter Files to Voron folder
    [OmronFotek90HeatsertV3.stl, OmronFotek90M2_V3.stl, OmronFotek90M3TapV3.stl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]
2022-03-18 fixed klipper configs
    [00-euclid_exampleV3.cfg, 00-euclid_exampleV4.cfg]
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2022-03-21 fixed boltholes on Voron
    [Ender3MountV8b.stl, VoronGantryMountRev2.stl, VoronGantryMountRev2.stp]
2022-03-24 Ender3 Fixes
    [Ender3MountAltV8.stl, Ender3MountV8.stl, M4_DblNut_Spacer_Handwheels.stl]
2022-03-29 cleaning up voron files
    [Trident_TopMountCloseV1.stl, Trident_TopMountDockCloseV1.stl]
2022-03-30 Added mirrored V1 Gantry & Shorty Gantry
    [TopMountDockCloseV1.1.stl, Trident_TopMountCloseV1.1Mirrored.stl, Trident_TopMountDockCloseV1.1Mirrored.stl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]
2022-04-05 replaced Ender folder
    [Ender3MountV8.stp, Ender3PartsPlate.stl, Ender3_Dock_Modular_All_Parts.stp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]
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2022-04-20 updated V4 cfg example to include start_print info
    [00-euclid_exampleV4.cfg, yolodubstep_macros.cfg, yolodubstep_vcore3_400.cfg]
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2022-05-13 fix open surface stps
    [CleanDock.stp, SingleM2.5Mount.stp]
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2022-06-17 macro corrections
    [RRF3_Example_Auto_Deploy_Probe_Fixed_Dock.g, RRF3_Example_Auto_Retract_Probe_Fixed_Dock.g]
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2022-06-27 broke apart voron all parts to stps
    [00-euclid_exampleV3.cfg, Ender3MountV8b.stl, Gantry_Face_Mount.stp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]
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2022-07-01 RRF3 Typo Correction Moving z Dock
    [RRF3_Example_Auto_Deploy_Probe_MovingZ_Dock.g]
2022-07-02 klipper variable type fixed
    [00-euclid_exampleV3.cfg, 00-euclid_exampleV4.cfg]
2022-07-05 No short cover that protect the probe when docked
    Only the two magnests are visible and a bit more sunk than cover
    [euclid_noshort_cover.stl]
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2022-07-25 Clean and simplify example Klipper config
    This is still based on my personal config, but with the more advanced
    stuff removed. If users want that stuff, they need to take the
    responsibility of configuring it themselves.
    [00-euclid_exampleV4.cfg]
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2022-08-15 revised Z move after probe
    revised Z move after probe to bed clearance to clear probe from bed
    [00-euclid_exampleV5.cfg]
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2022-10-25 Updated CW2 files, Omron Files
    Updated CW2 files, Omron Files
    [Clockwork2_Euclid_MGN12X_LEFT_Carriage_Ver2.stl, Clockwork2_Euclid_MGN12X_RIGHT_Carriage_Ver2.stl, Clockwork2_Left_Euclid_MGN12X_Cairriage.stl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]
2022-11-03 corrected V3 typos
    [00-euclid_exampleV3.cfg]
2022-11-09 corrected klipper example
    [00-euclid_exampleV3.cfg, Dust_Euclid_Dock.stl, Dust_Euclid_Gantry_Face_Mount.stl]
2023-02-16 Custom VZbot VZ-Printhead mount
    I've created a custom mount for the Euclid Probe for the VZ-Printhead. (Euclid mount VZ-printhead v5)
    It needs to be assembled onto the 5015 fan at the back.
    The dock that I used is the VoronGantyMountRev_4 filed down a little bit along with the RailCoreTopMountLong, assembled the other way to make the Mount fit.
    The image should make the assembly clearer.
    I've added the docks from the other repos here to make it easier to find the full assembly.
    [Euclid mount VZ-printhead v5.stl, RailCoreTopMountLong.stl, VoronGantryMountRev2_Short.stl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]
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2023-03-03 Excel Plotter, Updated Qidi Prts
    Excel Plotter, Updated Qidi Prts
    [00-euclid_exampleV5.cfg, DuctSupport.stl, Euclid_Macro_Path_Plot.xlsx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]
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2023-11-06 typos in klipper v3 config
    typos in klipper v3 config
    [00-euclid_exampleV3.cfg, Euclid_Macro_Path_Plot.xlsx, RailcoreMount713NativeV5_M3Holes.3mf]

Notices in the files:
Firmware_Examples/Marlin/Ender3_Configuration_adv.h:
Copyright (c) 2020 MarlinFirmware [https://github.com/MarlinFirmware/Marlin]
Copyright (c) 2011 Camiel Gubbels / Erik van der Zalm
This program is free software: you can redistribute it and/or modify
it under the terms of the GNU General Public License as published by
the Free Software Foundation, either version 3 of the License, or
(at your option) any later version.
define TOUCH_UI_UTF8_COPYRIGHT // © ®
